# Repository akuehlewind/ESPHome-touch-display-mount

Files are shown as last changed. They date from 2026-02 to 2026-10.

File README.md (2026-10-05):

# ESPHome Home Assistant Touch Panel – CYD, Guition 4.0 and External ILI9341






> [!TIP]
> **Want to build this kind of Home Assistant display, but with a much more powerful and user-friendly setup?**
>
> This repository gives you ready-to-flash YAML configurations and 3D-printable mounts. **Tessera** is a separate project by Max Gramser whose first version started from this repository and has since taken the idea much further: a visual drag-and-drop editor inside Home Assistant, multiple pages, richer controls, centralized screen management, broad display support, and normally no YAML or MQTT required.
>
> I am genuinely impressed by what Max and the community have built. If you want the most capable and polished version of this concept, this is the project I recommend.
>
> **[Discover Tessera: the next-level Home Assistant touchscreen project](https://github.com/MaxGramser/homeassistant_espscreen)**

**About this project:** This repository focuses on a straightforward DIY approach with ready-to-flash ESPHome configurations and 3D-printable mounts for Home Assistant touch panels. It supports the popular Cheap Yellow Display (ESP32-2432S028), the 4.0-inch Guition ESP32-4848S040C_I, and a standalone ILI9341 with external ESP32.

For the 2.8-inch displays, the repository also includes an adjustable 3D-printable enclosure. The existing mounts are designed for the CYD and standalone ILI9341 configurations; a Guition-specific mount is not included yet.

Multiple mounting options are supported:

- Desk Mount – for tabletop installation
- Under-Desk Mount – for installation underneath a desk or shelf
- Wall Mount – for wall installation (CYD version only)
- Flush Mount – for in-wall installation (EU electrical box compatible)

The enclosure can therefore be used as a compact Home Assistant control panel for desks, walls, or mounted underneath furniture.

------------------------------------------------------------------------

The ESP32-2432S028 Cheap Yellow Display is transformed into a tiltable Home Assistant control panel powered by ESPHome and LVGL.

The goal of this project is to create a clean, wall- or desk-mounted smart control panel that integrates seamlessly with Home Assistant.  
It features a modern LVGL-based UI, real-time state synchronization, and optional direct Home Assistant service calls.

The enclosure is designed for:

- Clean cable routing  
- Adjustable viewing angle (±35° tilt)  
- Minimal footprint  
- Professional, integrated appearance  

Three hardware variants are supported:

- ✅ **ESP32-2432S028 (Cheap Yellow Display / CYD)**
- ✅ **Standalone ILI9341 + External ESP32 wiring variant**
- ✅ **Guition ESP32-4848S040C_I (4.0-inch, 480×480, capacitive touch)** — home-like UI; firmware support only for now

The ESP32-2432S028 integrates the ESP32, ILI9341 display, touchscreen controller, and backlight circuitry on a single board.  
It is commonly known as the **Cheap Yellow Display (CYD)** in the maker community and is the easiest option for this project.

Some CYD boards use an ILI9342 panel. The existing CYD home-like YAML contains complete display/orientation presets for both ILI9341 and ILI9342; ILI9341 at 0 degrees remains active by default. USB connector type alone does not identify the controller. See the [hardware selection notes](esphome/home-like/README.md#picking-your-hardware-variant).

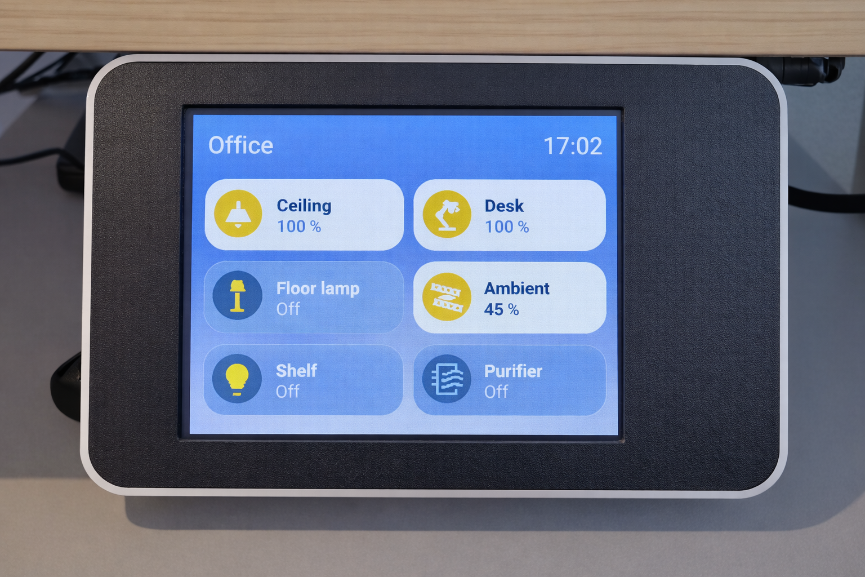
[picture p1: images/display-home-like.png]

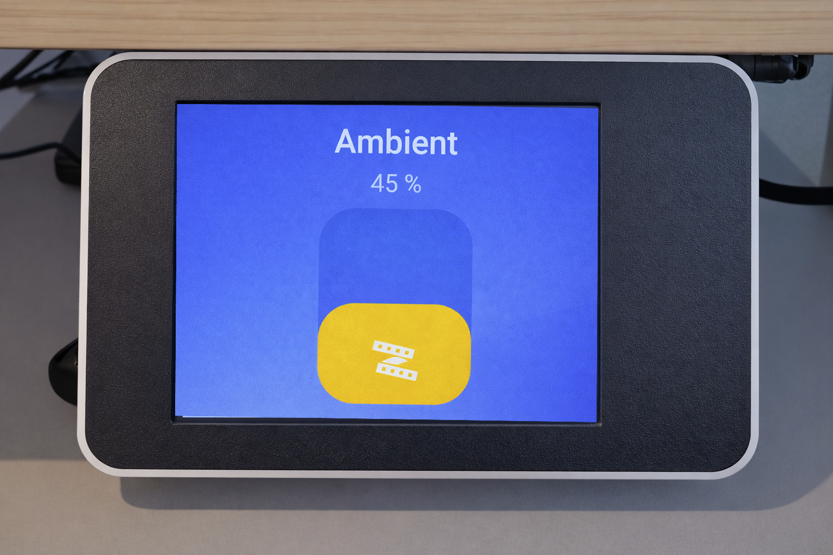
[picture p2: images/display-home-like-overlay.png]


### Guition ESP32-4848S040C_I

The Guition variant uses the same home-like interaction model in a larger 2×4 grid with eight configurable tiles. The tested orientation places the USB-C connector at the bottom.

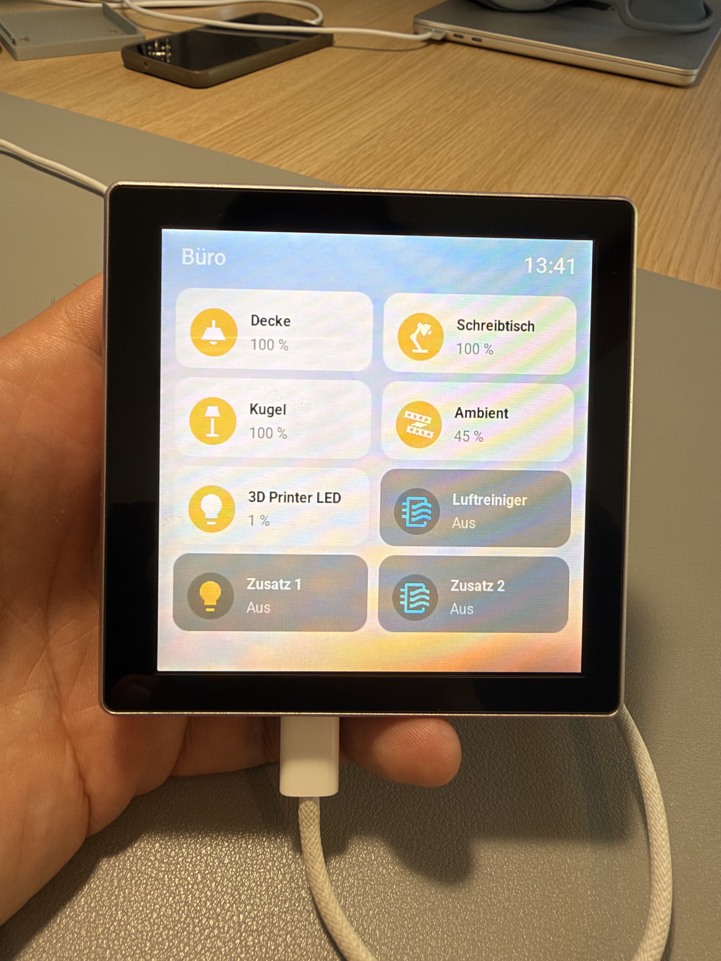
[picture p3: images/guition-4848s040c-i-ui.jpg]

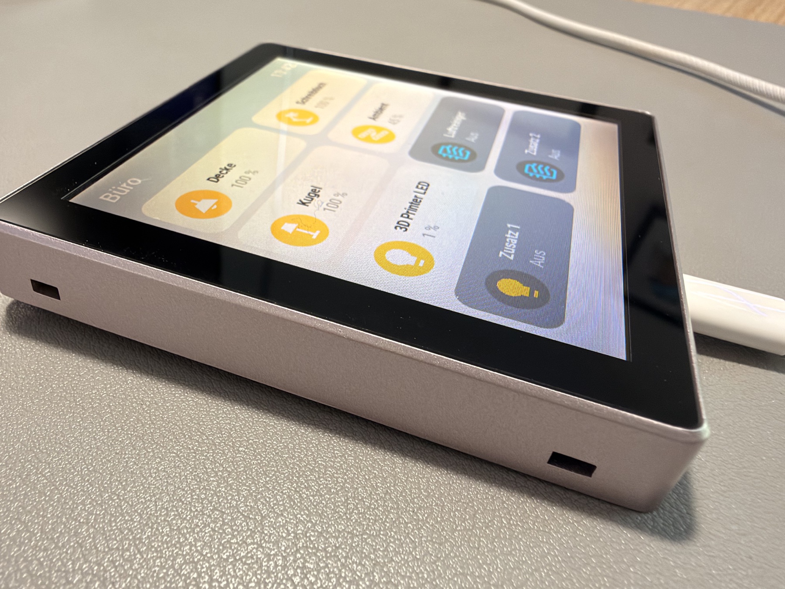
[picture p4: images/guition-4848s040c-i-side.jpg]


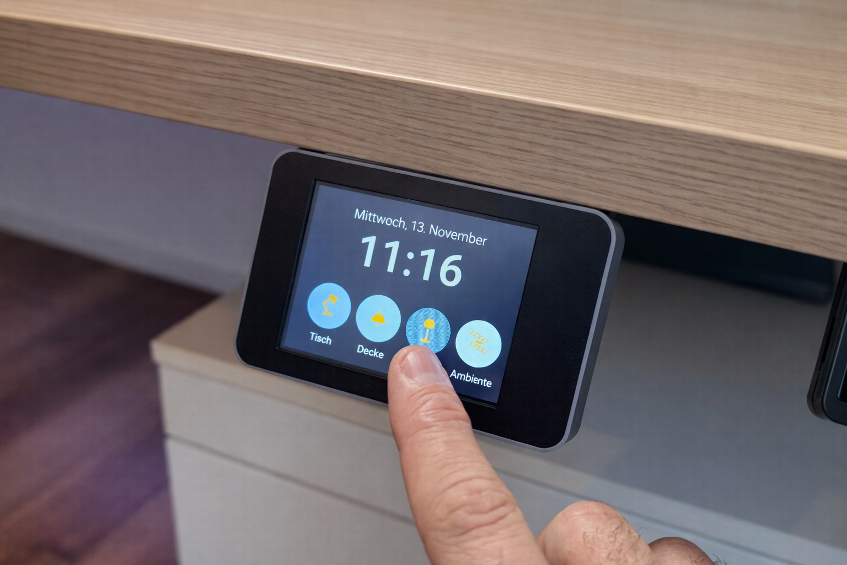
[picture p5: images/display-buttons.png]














## Demo
https://github.com/user-attachments/assets/68709d8e-21ec-4851-bf73-70f583027390

Note: The video quality looks worse than in real life because the display refresh rate interferes with the camera frame rate when filming the screen. In reality the UI looks much smoother and cleaner.

---

# 🆕 Architecture Overview (LVGL-Based UI)

This project uses ESPHome LVGL instead of a classic display lambda approach.

### Core Concepts

- UI rendered fully using LVGL widgets
- 4 configurable buttons in the simple UI, or 6/8 configurable tiles in the home-like UI
- Real-time state mirroring from Home Assistant
- Central `ui_refresh` script keeps UI synchronized
- Optional direct Home Assistant service calls
- Action sensor for automation-based control

### Two Control Modes

#### 1️⃣ Direct Mode (Default – Plug & Play)

If `DIRECT_ACTIONS` is set to `"true"` (default):

- Touch publishes an action string
- AND directly calls a Home Assistant service  
  (default: `light.toggle`)

No Home Assistant automations required.

#### 2️⃣ Automation Mode

If `DIRECT_ACTIONS` is set to `"false"`:

- Touch ONLY publishes an action string
- You implement behavior in Home Assistant automations

Trigger example:
```
Entity: sensor.smartdisplay_action
To: btn1_press
```

### Overlay Control Layer

The UI contains a secondary overlay layer used for interactive controls.

When a tile is long-pressed:

1. The overlay opens
2. The control type is determined (brightness / percentage / cover position / climate temperature)
3. For color-capable lights, the brightness overlay can open a color/temperature picker
4. Slider interaction updates Home Assistant
5. Closing the overlay returns to the tile grid

This keeps the tile UI clean while still allowing detailed control.

# ⚙️ Requirements

- Home Assistant installed
- ESPHome Add-on installed
- **ESPHome 2026.9.0 or newer** is required by encrypted OTA in all five configs. Existing devices need the [OTA migration](#encrypted-ota-and-migration) before using the final config wirelessly.
- Home Assistant 2026.2+
- Basic ESPHome knowledge
- 3D printer access (optional)

---

# 🧪 Tested With

The current home-like integration was hardware-tested with:

- **ESPHome 2026.9.0** and **Home Assistant 2026.2+**
- ESP32-2432S028 (Cheap Yellow Display / CYD) with ILI9341
- Guition ESP32-4848S040C_I with ST7701S RGB display and GT911 capacitive touch
- all existing tile actions and overlays, localized OFF confirmation, auto-dim/wake, touch alignment and encrypted OTA migration

Earlier releases were also tested on the standalone ILI9341 + XPT2046 wiring variant. The ILI9342 contribution author reported testing all four orientations; the integrated ILI9342 profile has not been independently hardware-verified by the maintainer.

# ⚠️ IMPORTANT -- Enable "Actions" in Home Assistant

Because this project uses:

```
homeassistant.action → light.toggle
```

You must allow the ESPHome device to perform Home Assistant service calls.

### How to enable:

1. Open Home Assistant  
2. Go to **Settings**  
3. Click **Devices & Services**  
4. Open the **ESPHome integration**  
5. Select your device  
6. Enable:

> "Allow the device to perform Home Assistant actions"

Without this setting, direct control will not work.

---

# ✨ Features

- LVGL-based UI (lockscreen or tile layout depending on configuration)
- 2×3 configurable tile layout on 320×240 hardware and 2×4 on the 480×480 Guition (home-like UI)
- Long-press per tile: value overlay (brightness / fan speed / cover position / climate temperature) or independent entity action
- Real-time state synchronization with Home Assistant
- Optional direct Home Assistant service calls
- Automation-based mode supported
- Adjustable 3D-printed enclosure
- Multiple mounting options: desk mount, under-desk mount, wall mount, and flush mount
- Hidden cable routing
- Works with CYD, Guition ESP32-4848S040C_I, or external ESP32 wiring

------------------------------------------------------------------------

# 📦 Hardware

## Option A -- ESP32-2432S028 (Cheap Yellow Display Board -- Recommended)

| Part | Price | Comment |
|---|---|---|
| ESP32-2432S028			 | 15$ | 2.8" ILI9341 with integrated ESP |
| 2x M4 3.5x16 screw (flathead)| 0.10$ | Screws to connect the mount case with the base  |

Advantages:

-   Single USB cable
-   Clean installation
-   No manual wiring
-   Widely available under the name "Cheap Yellow Display"

| ESP32-2432S028 | PIN | Comment |
|---|---|---|
| LCD | | |
| clk_pin | GPIO14 | SPI LCD Clock |
| mosi_pin | GPIO13 | SPI LCD MOSI (sometimes also labeled as SDI) |
| miso_pin 	 		 | GPIO12 | SPI LCD MISO (sometimes also labeled as SDO	 |
| cs_pin | GPIO15 | Display CS |
| dc_pin | GPIO2 | Display DC |
| Touchscreen | | |
| clk_pin | GPIO25 | SPI Touchscreen Clock |
| mosi_pin | GPIO32 | SPI Touchscreen MOSI (sometimes also labeled as DIN) |
| miso_pin | GPIO39 | SPI Touchscreen MISO (sometimes also labeled as DO)  |
| cs_pin | GPIO33 | Touchscreen CS |
| interrupt_pin | GPIO36 | Touchscreen Interrupt |
| LED | | |
| ledc | GPIO21 | Backlight LED display |
| ledc | GPIO4 | Onboard LED (not used for this project) |

------------------------------------------------------------------------

### Power connection (CYD)

For the mount enclosure the side USB connector of the CYD is **not used**.

Instead the included power cable can be used.  
The **red and black wires provide 5V and GND** and can easily be connected to an old USB-A cable.

Typical setup:

1. Cut an old USB cable
2. Connect **5V (red)** and **GND (black)** to the CYD power cable
3. Route the cable through the enclosure
4. Solder or use small wire connectors

This keeps the enclosure compact and avoids having a visible or protruding USB connector on the side.

If the USB port was used directly, the enclosure would need to be wider or the connector would remain visible.

⚠️ Important: The CYD often has multiple identical JST connectors, but they do not share the same pinout. Make sure to use the connector labeled VIN / 5V. Other connectors may be labeled 3.3V, and connecting 5V there can damage the board.



## Option B -- Standalone Display + ESP32

| Part | Price | Comment |
|---|---|---|
| 2.8" ILI9341 			 | 8$ | 2.8" ILI9341 |
| ESP32 Wroom 32D 		 | 8$ | or some ESP32 |
| 2x M4 3.5x16 screw (flathead)| 0.10$ | Screws to connect the mount case with the base  |

Requires manual wiring according to the YAML pin configuration.

Use the wiring table below, which shows how to put everything together.

| ILI9341 | PIN  ESP32 | Comment |
|---|---|---|
| GND | GND | Ground |
| VCC | 3.3V | Power |
| LCD | | |
| SCK | GPIO18 | SPI LCD Clock |
| SDI (MOSI) | GPIO23 | SPI LCD MOSI (sometimes also labeled as SDI) |
| SDO (MISO) 	 	 | GPIO19 | SPI LCD MISO (sometimes also labeled as SDO	 |
| CS | GPIO27 | Display CS |
| D/C | GPIO26 | Display DC |
| RESET | GPIO16 | Display Reset |
| Touchscreen | | |
| T_CLK | GPIO25 | SPI Touchscreen Clock |
| T_DO | GPIO35 | SPI Touchscreen MISO (sometimes also labeled as DO) |
| T_DIN | GPIO32 | SPI Touchscreen MOSI (sometimes also labeled as DIN)  |
| T_CS | GPIO33 | Touchscreen CS |
| T_IRQ | GPIO34 | Touchscreen Interrupt |
| LED | | |
| ledc | GPIO4 | Backlight LED display |

------------------------------------------------------------------------

## Option C -- Guition ESP32-4848S040C_I

The Guition is an all-in-one ESP32-S3 board with a 4.0-inch 480×480 ST7701S RGB display, GT911 capacitive touchscreen, 16 MB flash, and 8 MB octal PSRAM. Use `esphome/home-like/guition-4848s040c-i/home-like.yaml`; its display timings, touch transform, and USB-C-down orientation are already configured.

No manual display wiring is required. The existing 2.8-inch printable enclosures do not fit this board.

------------------------------------------------------------------------

# 🚀 Installation

1.  Open ESPHome in Home Assistant
2.  Create a new device
3.  Copy the appropriate YAML file
4.  Edit the **USER CONFIG / substitutions** section at the top of the YAML (entities, labels, icons)
5.  Copy `esphome/secrets.yaml.example` to `secrets.yaml` **in the same directory as the chosen YAML** and fill in your credentials
6.  Flash the device; for an existing password-based installation, follow [OTA migration](#encrypted-ota-and-migration)

Available YAML variants (pick **one UI** for your **hardware**):

> **ESPHome version:** all configs require **ESPHome 2026.9.0+**. The CYD ILI9341 and Guition home-like configurations have been verified on hardware; see [Tested With](#-tested-with) for the remaining hardware scope.

### Cheap Yellow Display (ESP32-2432S028 / CYD)
- `esphome/home-like/cyd-2432s028/home-like.yaml` – 2x3 “tiles” UI (wallpaper + tiles) — actively maintained
- `esphome/buttons/cyd-2432s028/buttons.yaml` – lockscreen with 4 round buttons (simple / legacy)

### External display wiring (any ESP32 + ILI9341 + XPT2046)
- `esphome/home-like/ili9341-external-esp32/home-like.yaml` – 2x3 “tiles” UI (wallpaper + tiles) — actively maintained
- `esphome/buttons/ili9341-external-esp32/buttons.yaml` – lockscreen with 4 round buttons (simple / legacy)

### Guition ESP32-4848S040C_I
- `esphome/home-like/guition-4848s040c-i/home-like.yaml` – 2x4 home-like UI with 8 tiles — actively maintained and hardware-tested

> Tip: The `home-like.yaml` file downloads orientation-specific background images at build time from a pinned repository revision.
> For a full reference of all tile substitutions and copy-paste examples, see [`esphome/home-like/TILE_CONFIGURATION.md`](esphome/home-like/TILE_CONFIGURATION.md).
> Three images are included:
> - `smartdisplay_background.png` — used for 0° (landscape) and 180° (landscape flipped)
> - `smartdisplay_background_90.png` — used for 90° (portrait) and 270° (portrait flipped)
> - `smartdisplay_background_480.png` — square Guition background
>
> The active image is selected via the `BG_IMAGE` substitution. On the 320×240 variants it belongs to the selected orientation preset; the Guition config uses its fixed square background.

------------------------------------------------------------------------

### Assets (downloaded at build time)

The icon font and home-like wallpapers download during compilation, so they do not need to be copied alongside the YAML for the default setup. Credentials still belong in `secrets.yaml` next to that YAML. Existing Google Fonts entries also need network access at build time.

- **Material Design Icons font**: `MDI_FONT_URL` points to `materialdesignicons-webfont.ttf` at release **v7.4.47** of [Templarian/MaterialDesign-Webfont](https://github.com/Templarian/MaterialDesign-Webfont) (Apache 2.0).
  - If you change icons in the YAML, ensure the glyph list contains them.
- **Background images (home-like UI)**:
  - `esphome/home-like/images/smartdisplay_background.png` — landscape (0° and 180°), included.
  - `esphome/home-like/images/smartdisplay_background_90.png` — portrait (90° and 270°), included.
  - `esphome/home-like/images/smartdisplay_background_480.png` — 480×480 Guition, included.
  - Selected via the `BG_IMAGE` substitution; the 320×240 variants tie it to the active orientation preset.
  - Every `ASSET_BASE` is pinned to an immutable repository commit under `esphome/home-like`, so it does not follow changes on `main`. The 320×240 variants use `9ffa5dfddf695150ad0388f5f5e2bcf786772195`; the Guition variant uses `cb3531a7fdf057d4b7273d1feba648162bcfd5c9`.

For local home-like assets, copy that UI's `images/` and `fonts/` folders next to the chosen YAML and set these substitutions:

```yaml
ASSET_BASE: '.'
MDI_FONT_URL: 'fonts/materialdesignicons-webfont.ttf'
```

The buttons UI only needs the font override and local `fonts/` folder; it has no wallpaper. These overrides do not replace the Google Fonts downloads.

### Encrypted OTA and migration

Current configs use `ota: - platform: esphome` with `encryption:`, inheriting `smartdisplay_api_key` from API encryption. Keep the existing API key.

For firmware that only supports password-based OTA, use **two wireless installs** with ESPHome 2026.9.x:

1. In your local config, temporarily replace OTA `encryption:` with `password: !secret ota_password`. Keep the existing password in the adjacent `secrets.yaml` and API encryption enabled. Install, reboot, and verify the log says `Encryption: offered, plaintext accepted`.
2. Replace OTA `password:` with the bare `encryption:` block below, then install again. Verify `Encryption: required`. Subsequent OTA updates use encryption; the unused OTA password secret can now be removed.

```yaml
ota:
  - platform: esphome
    encryption:
```

Do not combine OTA `password:` and `encryption:`. The first transfer to old firmware is plaintext. Alternatively, install the final encrypted config directly over USB/serial. See [ESPHome's migration instructions](https://esphome.io/components/ota/esphome/#enabling-encryption-on-an-existing-device).

# ⚙️ UI mapping (USER CONFIG)

Your config choice defines the UI style:

## `buttons.yaml` (lockscreen like buttons)
- Buttons: BTN1..BTN4
- Action strings: `btn1_press` .. `btn4_press`
- Default direct action (if `DIRECT_ACTIONS: "true"`): `light.toggle` on `BTN*_ENTITY`



## `home-like.yaml` (tiles)
- Tiles: TILE1..TILE6 on 320×240 variants; TILE1..TILE8 on Guition
- Action strings follow the configured tile range, e.g. `tile1_press` through `tile8_press` and the corresponding `tileN_long_press` events
- Each tile can optionally call a Home Assistant service directly (e.g. light toggle, fan preset toggle, cover open/close, cover position, or climate target temperature).
- Per-tile OFF label is configurable via `TILE*_LABEL_OFF` (e.g. "Off" / "Aus").
- Optional `TILEn_CONFIRM_OFF: "true"` guards short taps that would turn off or close a supported entity; the default is `"false"`. Cancellation emits no event and performs no action. Acceptance publishes `tileN_confirmed_off` and performs an explicit off/close action instead of a toggle. See [supported actions and limitations](esphome/home-like/TILE_CONFIGURATION.md#short-tap-off-confirmation), including automation-only mode and unprotected long presses.

### Long-Press Behavior

Each tile's long-press mode is configured via `TILE*_LONGPRESS`:

| Mode | Behavior |
|---|---|
| `slider` | Opens a value overlay (brightness / fan speed / cover position / climate temperature) |
| `action` | Fires a different HA entity than the short tap |
| `none` | Only publishes the `tileN_long_press` event, no direct action |

**Slider mode** — configure with `TILE*_LONGPRESS_SLIDER` and `TILE*_LONGPRESS_OFF_VALUE`:

| Tile Type | Overlay Control |
|---|---|
| light | Brightness slider; color/temperature picker when supported by the HA light entity |
| fan | Speed / percentage slider |
| cover | Position slider |
| climate | Thermostat ring for target temperature |

**Action mode** — configure with `TILE*_LONGPRESS_ACTION`, `TILE*_LONGPRESS_ACTION_TYPE`, and optionally `TILE*_LONGPRESS_ACTION_SERVICE`. The action entity can be a completely different entity than the short tap target — useful for e.g. triggering a scene or script on long press while toggling a light on short press.

In all modes, the `tileN_long_press` event is always published to `sensor.smartdisplay_action` so Home Assistant automations can react to it independently.




------------------------------------------------------------------------

# 🧠 System Flow

### Direct Mode

For a guarded home-like short tap that would switch an entity off, confirmation happens before step 2. Acceptance publishes `tileN_confirmed_off`; cancellation stops the flow.

1. Button pressed  
2. Action string published  
3. Home Assistant service called  
4. Entity state updated  
5. Mirrored back into ESPHome  
6. UI refreshed  

### Automation Mode

The same short-tap gate replaces the normal event with `tileN_confirmed_off` after acceptance. The automation must handle that event with an explicit off/close service, not a toggle.

1. Button pressed  
2. Action string published  
3. Home Assistant automation triggers  
4. Automation controls device  
5. State mirrored back  

------------------------------------------------------------------------

# 🔧 Customization

For most setups, you only need to edit the **USER CONFIG / substitutions** section in the YAML.

You can also:

-   Add more buttons / pages
-   Change service calls (the default is `light.toggle`)
-   Modify fonts and icon glyphs
-   Adjust colors / theme
-   Date localization can be adjusted in the ui_refresh script (days[] / months[] arrays).
-   Adjust transforms for your panel

For home-like touch alignment, use the matching hardware profile and ORIENTATION preset first. LVGL rotates the display and touch coordinates together; touchscreen transforms correct the controller's native axes and do not need to match a display transform. Tune `TOUCH_CAL_*` for your panel.

------------------------------------------------------------------------
# Troubleshooting

### White screen after ESPHome update (2026.4+)

If the display stays **completely white** after updating ESPHome but the device still connects to Home Assistant, the cause is a breaking change in ESPHome 2026.4: the `ili9xxx` display platform was deprecated in favor of `mipi_spi`.

The current configs use `mipi_spi` and require ESPHome 2026.9.0+ for encrypted OTA. Upgrade the builder and follow the OTA migration above; reverting only the display platform does not make these configs compatible with older releases.

---

### Corrupted / garbled display output

If the display shows **corrupted graphics, horizontal lines, or random pixels**, the most common cause is a **different display controller on your Cheap Yellow Display**.

Most CYD boards use **ILI9341**, but some variants ship with **ST7789** or **ILI9342**.  
If the driver in ESPHome does not match the controller, the display output may look broken.

For a confirmed ILI9342 panel, use the existing `esphome/home-like/cyd-2432s028/home-like.yaml`. In **DISPLAY / ORIENTATION PRESETS**, comment out the active ILI9341 block and uncomment one complete ILI9342 block for the required orientation. No separate ILI9342 YAML is needed and no calculated substitutions are involved.

Diagonal stripes can indicate a mismatch between the native panel dimensions and driver. Check the board/controller information; neither that symptom nor a USB-C/Micro-USB connector arrangement is definitive identification. ST7789 boards need a separately verified configuration and are not covered by the ILI9341/ILI9342 selector. The selector applies to the CYD home-like config, not the buttons or external-wiring variants.

---

### `Invalid offsets.` / won't compile on ESPHome 2026.6+

If validation fails on the `dimensions:` line of the display with:

```
display.mipi_spi: Invalid offsets.
```

this is the ESPHome 2026.6 change to `mipi_spi`: a `transform:` block on the display combined with swapped (rotated) `dimensions:` is no longer accepted. **The configs in this repo are already fixed for this** — rotation is now handled by LVGL:

- the display is driven at its **native** size (240 × 320 for ILI9341; 320 × 240 for ILI9342) with **no** rotation transform on the display
- rotation is set via `LVGL_ROTATION` in the chosen ORIENTATION preset, which feeds `rotation:` in the `lvgl:` block (LVGL rotates the display **and** the touch coordinates together)

If you copied an older YAML, update your device configuration, compile with ESPHome 2026.9.0+, and install it using the appropriate migration path above.

---

### Display rotated / mirrored

If the UI appears **rotated, mirrored, or upside down**, use the built-in **DISPLAY / ORIENTATION PRESETS** in the substitutions section at the top of `home-like.yaml`.

The CYD home-like config provides eight complete presets: four orientations for ILI9341 and four for ILI9342. Uncomment exactly one complete block and comment out all others. The external ILI9341 config continues to provide its four orientation presets.

> Note: touch calibration values (`TOUCH_CAL_*`) are device-specific. The presets include approximate values that may need tuning after flashing.

**LVGL manages rotation** for both the display and the touchscreen. Do not add display rotation to compensate for touch alignment; use the matching profile and preset. The resulting rotation is supplied through `LVGL_ROTATION`:

```yaml
# in the active display/orientation preset
LVGL_ROTATION: "90"   # 0 / 90 / 180 / 270
```

If touch is mirrored or axes are swapped relative to the display, check the touchscreen axis correction for your selected controller. These values correct raw XPT2046 coordinates against the native panel; the ILI9341 example below is not a universal ILI9342 profile:

```yaml
TOUCH_SWAP_XY: "false"
TOUCH_MIRROR_X: "true"
TOUCH_MIRROR_Y: "false"
```

After changing a display/orientation preset, verify touch targets and calibration on the physical panel. Current configs require ESPHome 2026.9.0+.

------------------------------------------------------------------------

# 🖨 3D Printing

See the `/3d_print` folder for STL files and Fusion 360 source files.

Multiple mount options are available:

- **Desk Mount** – for tabletop installation
- **Under-Desk Mount** – for installation underneath a desk or shelf
- **Wall Mount** – for wall installation (CYD version only)
- **Flush Mount** – for in-wall installation (CYD version only, EU electrical box compatible)

Desk mount and Under-Desk mount use the same enclosure parts and adjustable tilt mechanism.  
Print the main enclosure parts and choose one mount type depending on your setup.

Designed for:

- Desk mounting
- Under-desk mounting
- Wall mounting
- Flush mounting (EU electrical box compatible)
- Adjustable viewing angle
- Hidden cable routing

------------------------------------------------------------------------

# ⚠️ Disclaimer

This is a hobby project and considered work-in-progress.

Feel free to fork, remix and improve it.

# Other





# More projects
Looking for more cool projects using this display? Check out the [LoctekMotion Touch Display GitHub repository](https://github.com/3DJupp/LoctekMotion-TouchDisplay)! This awesome project takes the same 2.8" ILI9341 touchscreen setup and repurposes it—not for lights, but for controlling a height-adjustable Flexispot desk with ease. If you're into smart home automation and custom builds, it's definitely worth a look!

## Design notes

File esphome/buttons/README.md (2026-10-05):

# Buttons UI — Simple Lockscreen Layout

This folder contains the original "buttons" UI: a minimal lockscreen with a clock and 4 round toggle buttons.

Requires **ESPHome 2026.9.0 or newer**. Existing password-based devices need the [two-step wireless OTA migration](../../README.md#encrypted-ota-and-migration), or a USB/serial install.

> **Looking for the full-featured UI?**
> The actively maintained version is in [`../home-like/`](../home-like/).
> It offers a 2×3 or 2×4 tile grid depending on hardware, per-tile entity types, brightness/fan/cover sliders, long press actions, orientation presets, and much more.

---

## What this UI does

- Displays a clock (time + date)
- 4 configurable round buttons, each mapped to a Home Assistant entity
- Each tap publishes `btn1_press` … `btn4_press` to `sensor.smartdisplay_action`
- Optional direct HA service calls (light.toggle by default)

## What it does NOT have

- No tile grid or wallpaper background
- No per-button entity types (lights only by default)
- No value/state display per button
- No brightness, fan speed, or cover position sliders
- No long press actions
- No orientation presets
- No auto-dim or night mode
- No per-tile OFF confirmation or ILI9342 model selector; those belong to the home-like UI

## When to use it

If you want the absolute simplest possible setup — just 4 buttons that toggle lights — this is the quickest way to get started. Configuration is minimal: set 4 entity IDs and flash.

For anything beyond basic toggles, use the [home-like UI](../home-like/) instead.

## Picking your hardware variant

You need to pick **one** YAML file that matches your hardware:

### `cyd-2432s028/buttons.yaml` — Cheap Yellow Display (CYD)

The **ESP32-2432S028**, commonly known as the **Cheap Yellow Display (CYD)**, is an all-in-one board with the ESP32, ILI9341 display, XPT2046 touchscreen, and backlight all on a single PCB. Just one USB cable, no manual wiring.

### `ili9341-external-esp32/buttons.yaml` — Standalone ILI9341 + external ESP32

Use this file if you have a **separate ILI9341 display module** wired to a generic ESP32 board. Requires manual wiring according to the pin table in the main README.

---

## Credentials — secrets.yaml

All sensitive values (API key and WiFi credentials) are referenced via ESPHome's `!secret` system. Encrypted OTA inherits the API encryption key.

Copy [`../secrets.yaml.example`](../secrets.yaml.example) to `secrets.yaml` **in the same directory as the chosen YAML**, and fill in your values. For example, `cyd-2432s028/buttons.yaml` needs `cyd-2432s028/secrets.yaml`. `secrets.yaml` is gitignored and never committed. Keep the old OTA password secret only for the first wireless migration step.

---

## Assets downloaded at build time

The icon font downloads at build time through `MDI_FONT_URL`, pinned to Material Design Webfont **v7.4.47**. The buttons UI has **no wallpaper and needs no background image**.

For a local icon font, copy the bundled `fonts/` folder next to the chosen YAML and set:

```yaml
MDI_FONT_URL: 'fonts/materialdesignicons-webfont.ttf'
```

Existing Google Fonts entries still require network access at build time. Both button configurations are compile-validated with ESPHome 2026.9.0; the current integration was hardware-tested with the home-like CYD UI, not this legacy UI.

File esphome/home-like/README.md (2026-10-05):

# Home-Like UI — Tile Grid Layout

This folder contains the main, actively maintained UI: a wallpaper-backed tile grid inspired by modern smart home apps. The 320×240 variants use a 2×3 grid; the Guition 480×480 variant uses a 2×4 grid.

Requires **ESPHome 2026.9.0 or newer**. For existing password-based devices, follow the [two-step wireless OTA migration](../../README.md#encrypted-ota-and-migration), or install over USB/serial.

> **Looking for the simple version?**
> A minimal lockscreen with 4 round buttons is available in [`../buttons/`](../buttons/).

---

## What this UI does

- 6 or 8 configurable tiles, depending on the hardware variant, each with icon, title, and value line
- Supports lights, fans, switches, covers, climate entities, scenes, and scripts per tile
- Real-time state synchronization with Home Assistant
- Long press opens a value overlay (brightness / fan speed / cover position / climate temperature)
- Color-capable lights can open a color/temperature picker from the brightness overlay
- Long press can alternatively fire a completely different HA entity than the short tap
- Four orientation presets on the 320×240 variants; a hardware-tested USB-C-down orientation on Guition
- Auto-dim and night mode with configurable brightness levels
- Optional direct HA service calls or automation-only mode
- Optional short-tap OFF confirmation per tile; defaults to disabled and leaves long presses independent

---

## Configuration reference

All tile substitutions are documented in [TILE_CONFIGURATION.md](TILE_CONFIGURATION.md). It covers:

- Every substitution key with description and default value
- All tap actions, long press modes, and value modes explained
- Complete copy-paste examples for: light, switch, cover, fan, climate, scene, script
- Long press examples: slider overlay and independent entity action
- How to find and format Material Design Icons

Start there if you are setting up tiles for the first time.

---

## Picking your hardware variant

You need to pick **one** YAML file that matches your hardware:

### `cyd-2432s028/home-like.yaml` — Cheap Yellow Display (CYD)

The **ESP32-2432S028**, commonly known as the **Cheap Yellow Display (CYD)**, is an all-in-one board with the ESP32, ILI9341 display, XPT2046 touchscreen, and backlight all on a single PCB. It is the easiest and most common choice for this project — just one USB cable, no manual wiring.

Use this file if you have a standalone ESP32-2432S028 board.

In the **DISPLAY / ORIENTATION PRESETS** section, enable exactly one complete block for the controller and orientation you need. `ILI9341 / 0 degrees` is active by default; every ILI9342 block is fully commented out. There is no separate ILI9342 copy and no template logic to edit. Check the actual controller: USB connector type alone is not definitive, and ST7789 variants are not supported by these presets.

| Setting | ILI9341 (default) | ILI9342 |
|---|---|---|
| Native dimensions | 240 x 320 | 320 x 240 |
| Display data rate / color order | 10 MHz / BGR, preserving existing behavior | 40 MHz / RGB |
| LVGL rotation relative to orientation | +90 degrees, modulo 360 | +180 degrees, modulo 360 |
| Touch swap X/Y | false | true |
| Touch mirror X / Y | true / false | true / true in landscape; false / false in portrait |
| Touch calibration X / Y minima | 280 / 340 | 340 / 280 |

The ILI9342 contributor reported testing all four orientations on hardware. Its touch mirror settings are empirical, particularly in portrait; a source audit cannot independently verify touch alignment. Hardware verification of the integrated profile by the maintainer is **pending**, so check touch targets and calibration on your own panel. ILI9341 remains the default with its existing settings and behavior.

### `ili9341-external-esp32/home-like.yaml` — Standalone ILI9341 + external ESP32

Use this file if you have a **separate ILI9341 display module** wired to a generic ESP32 board (e.g. ESP32 DevKit / Wroom 32D). This requires manual wiring according to the pin table in the main README.

### `guition-4848s040c-i/home-like.yaml` — Guition 4.0-inch 480×480

Use this file for the **Guition ESP32-4848S040C_I** with ESP32-S3, ST7701S RGB display, and GT911 capacitive touchscreen. It provides eight tiles in a 2×4 grid. The display timings, touch transform, full LVGL buffer, and USB-C-down orientation were verified on physical hardware with ESPHome 2026.9.0.

This variant currently adds firmware/UI support only. The repository's existing 3D-printable enclosures are sized for the 2.8-inch displays and do not fit the Guition board.

---

## Credentials — secrets.yaml

All sensitive values (API key and WiFi credentials) are referenced via ESPHome's `!secret` system, so nothing sensitive is stored in the YAML itself. Encrypted OTA inherits the API key.

Copy [`../secrets.yaml.example`](../secrets.yaml.example) to `secrets.yaml` **next to the chosen YAML**, and fill in your values. For example, a config kept at `cyd-2432s028/home-like.yaml` needs `cyd-2432s028/secrets.yaml`. When pasted into Device Builder, use the directory containing that device's YAML.

```yaml
wifi_ssid: "Your WiFi Network Name"
wifi_password: "your_wifi_password"
smartdisplay_api_key: "your_32_byte_base64_api_key"
wifi_ap_password: "your_fallback_password"
```

`secrets.yaml` is gitignored and never committed.

Retain the existing `ota_password` secret only while performing step 1 of the [wireless migration](../../README.md#encrypted-ota-and-migration); the final encrypted config does not use it.

---

## Assets downloaded at build time

The default config downloads its icon font and wallpapers while compiling. No local asset folders are required for this setup; `secrets.yaml` is still required alongside the YAML.

| Substitution | Source | Required by |
|---|---|---|
| `MDI_FONT_URL` | Templarian/MaterialDesign-Webfont release `v7.4.47` | Icon glyphs on every tile |
| `ASSET_BASE` | This repository's `esphome/home-like` at the immutable commit selected in each YAML | Background wallpaper |

The 320×240 variants pin `ASSET_BASE` to commit `9ffa5dfddf695150ad0388f5f5e2bcf786772195`. The Guition variant pins it to the asset commit `cb3531a7fdf057d4b7273d1feba648162bcfd5c9` containing its square background.

- `smartdisplay_background.png` — used for 0° and 180° (landscape)
- `smartdisplay_background_90.png` — used for 90° and 270° (portrait)
- `smartdisplay_background_480.png` — used by the square Guition variant

The active image is selected by `BG_IMAGE` in the chosen display/orientation preset inside the YAML.

To use the bundled assets locally, copy this folder's `fonts/` and `images/` next to your chosen YAML and override:

```yaml
ASSET_BASE: '.'
MDI_FONT_URL: 'fonts/materialdesignicons-webfont.ttf'
```

These overrides only localize the icon font and wallpapers. The existing Google Fonts entries still require network access during compilation.

## Short-tap confirmation

Set `TILEn_CONFIRM_OFF: "true"` for a tile that should ask before turning off or closing. It is independent of `TILEn_TAP_ACTION` and defaults to `"false"`. Cancellation, tapping outside, or display dimming emits no event and performs no action. Acceptance publishes `tileN_confirmed_off` and uses an explicit `turn_off`/`close_cover` action, so a state change while the dialog is open cannot turn the entity back on.

The alert question, actions, color controls, and climate labels are localizable through the `UI_*` substitutions. Confirmation questions contain a `{title}` placeholder, which may be moved to match the target language's word order. A complete German example is included in [the configuration reference](TILE_CONFIGURATION.md#interface-text-and-localization).

The guard covers built-in toggle behavior for lights, fans, switches and covers, `fan_toggle_preset`, matching toggle services, and explicit off/close services. Unknown states are treated as potentially on. Scenes, scripts, climate tiles and opaque custom services are not gated because the display cannot know whether they switch something off. Long presses remain independent and are **not protected**. In automation-only mode, handle `tileN_confirmed_off` with an idempotent off/close service. See [the full scope and example](TILE_CONFIGURATION.md#short-tap-off-confirmation).

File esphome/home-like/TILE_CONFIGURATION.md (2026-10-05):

# Tile Configuration Reference

This document explains every substitution in `home-like.yaml` and provides copy-paste examples for all supported entity types.

---

## How substitutions work

ESPHome substitutions are compile-time text replacements. There is no runtime logic in the substitution block — every `${TILE1_...}` reference in the YAML is replaced with the value you set before the firmware is compiled and flashed. This means:

- You cannot use `if/else` in substitutions
- Changes require a reflash
- The firmware is fully self-contained after flashing

---

## Global settings

| Key | Default | Description |
|-----|---|---|
| `DIRECT_ACTIONS` | `"true"` | `true` = device calls HA services directly on tap. `false` = only publishes the action event, you handle it in HA automations. |
| `ROOM_NAME` | `"Office"` | Text shown in the top-left header. |
| `TIME_24H` | `"true"` | `true` = 24h clock, `false` = 12h with AM/PM. |
| `AUTO_DIM` | `"true"` | Enable backlight auto-dimming after inactivity. |
| `AUTO_DIM_TIMEOUT` | `"10"` | Seconds of no touch before dimming. |
| `MAX_BRIGHTNESS` | `"100"` | Backlight brightness (%) when active. |
| `DIM_BRIGHTNESS` | `"40"` | Backlight brightness (%) when dimmed. |
| `NIGHT_MODE` | `"true"` | Use a lower brightness level during night hours. |
| `NIGHT_START_HOUR` | `"22"` | Hour (0–23) when night mode starts. |
| `NIGHT_END_HOUR` | `"7"` | Hour (0–23) when night mode ends. |
| `NIGHT_DIM_BRIGHTNESS` | `"18"` | Backlight brightness (%) during night hours. |

---

## Interface text and localization

All built-in overlay text is configured through `UI_*` substitutions. This keeps translations in the editable configuration and does not require language-specific branches in the implementation. Tile titles and on/off labels remain configurable per tile.

The confirmation questions use `{title}` as a required placeholder. It may appear anywhere in the sentence, so languages can use their natural word order. For example:

```yaml
UI_CONFIRM_OFF_QUESTION: "{title} ausschalten?"
UI_CONFIRM_CLOSE_QUESTION: "{title} schließen?"
UI_CONFIRM_FALLBACK_TITLE: "dieses Gerät"
UI_CANCEL: "Abbrechen"
UI_TURN_OFF: "Ausschalten"
UI_CLOSE: "Schließen"
```

The complete interface text set is:

| Substitution | Default | Used for |
|---|---|---|
| `UI_CONFIRM_OFF_QUESTION` | `Turn off {title}?` | Light, fan and switch confirmation |
| `UI_CONFIRM_CLOSE_QUESTION` | `Close {title}?` | Cover confirmation |
| `UI_CONFIRM_FALLBACK_TITLE` | `this device` | Missing tile title in a confirmation |
| `UI_CANCEL` | `Cancel` | Non-destructive alert action |
| `UI_TURN_OFF` | `Turn off` | Destructive OFF action |
| `UI_CLOSE` | `Close` | Destructive cover action |
| `UI_COLOR` | `Color` | Color picker heading |
| `UI_TEMPERATURE_SHORT` | `Temp.` | Color-temperature heading |
| `UI_BRIGHTNESS` | `Brightness` | Brightness heading |
| `UI_CURRENT` | `Current` | Current climate value |
| `UI_HUMIDITY` | `Humidity` | Climate humidity value |
| `UI_SET_TO` | `SET TO` | Climate target value |
| `UI_CLIMATE_MODE_OFF` | `Off` | Climate mode |
| `UI_CLIMATE_MODE_HEAT` | `Heat` | Climate mode |
| `UI_CLIMATE_MODE_COOL` | `Cool` | Climate mode |
| `UI_CLIMATE_MODE_HEAT_COOL` | `Heat/Cool` | Climate mode |
| `UI_CLIMATE_MODE_AUTO` | `Auto` | Climate mode |
| `UI_CLIMATE_MODE_DRY` | `Dry` | Climate mode |
| `UI_CLIMATE_MODE_FAN` | `Fan` | Climate mode |

Changes are applied when the firmware is compiled. Keep translations concise for the target display and test long tile titles in the confirmation alert.

---

## Per-tile substitutions

Each tile has the same set of keys, just with a different number. The 320×240 variants provide TILE1 … TILE6; the Guition 480×480 variant provides TILE1 … TILE8.

### Basic settings

| Key | Description |
|-----|---|
| `TILE*_ENTITY` | The Home Assistant entity this tile controls (e.g. `light.living_room`). |
| `TILE*_STATE_ENTITY` | Entity used to determine active/inactive visual state. Usually the same as `TILE*_ENTITY`. Set to a different entity if you want the tile to reflect a group or a related sensor. |
| `TILE*_TITLE` | Text label shown on the tile. |
| `TILE*_ICON` | Material Design Icons Unicode glyph. Find icons at [pictogrammers.com/library/mdi](https://pictogrammers.com/library/mdi/) — click an icon and copy the Unicode value (e.g. `U+F0769` → `"\U000F0769"`). |
| `TILE*_TYPE` | Entity type: `light` \| `fan` \| `switch` \| `scene` \| `script` \| `cover` \| `climate`. Controls tap behavior, value display, and slider type in auto mode. |
| `TILE*_TAP_ACTION` | What happens on short tap — see [Tap actions](#tap-actions) below. |
| `TILE*_CONFIRM_OFF` | `"false"` by default. Set `"true"` to enable the [short-tap confirmation guard](#short-tap-off-confirmation), independently of the tap action. |
| `TILE*_LONGPRESS` | What happens on long press — see [Long press modes](#long-press-modes) below. |
| `TILE*_VALUE_MODE` | How the value line below the title is rendered — see [Value modes](#value-modes) below. |
| `TILE*_LABEL_OFF` | Text shown in the value line when the entity is off / inactive. |
| `TILE*_LABEL_ON` | Text shown in the value line when `VALUE_MODE` is `text` and entity is on. |

### Colors

All colors are 24-bit hex in the format `"0xRRGGBB"`.

| Key | Description |
|-----|---|
| `TILE*_CIRCLE_ACTIVE_COLOR` | Icon circle background when active. |
| `TILE*_CIRCLE_DISABLED_COLOR` | Icon circle background when inactive. |
| `TILE*_ICON_ACTIVE_COLOR` | Icon glyph color when active. |
| `TILE*_ICON_DISABLED_COLOR` | Icon glyph color when inactive. |
| `TILE*_BG_ACTIVE_COLOR` | Tile background when active. |
| `TILE*_BG_DISABLED_COLOR` | Tile background when inactive. |
| `TILE*_TITLE_ACTIVE_COLOR` | Title text color when active. |
| `TILE*_TITLE_DISABLED_COLOR` | Title text color when inactive. |
| `TILE*_VALUE_ACTIVE_COLOR` | Value text color when active. |
| `TILE*_VALUE_DISABLED_COLOR` | Value text color when inactive. |

### Advanced settings (short tap)

| Key | Default | Description |
|-----|---|---|
| `TILE*_TAP_SERVICE` | `""` | Override the HA service called on tap (e.g. `"light.toggle"`). Leave empty to use the default for the tile type. |
| `TILE*_TAP_PARAM_KEY` | `""` | Extra parameter key for the service call (e.g. `"preset_mode"`). |
| `TILE*_TAP_PARAM_VAL` | `""` | Extra parameter value (e.g. `"Auto"`). |

### Advanced settings (long press — slider mode)

Only relevant when `TILE*_LONGPRESS` is set to `"slider"`.

| Key | Default | Description |
|-----|---|---|
| `TILE*_LONGPRESS_SLIDER` | `"auto"` | Slider type: `auto` \| `brightness` \| `percentage` \| `cover_position` \| `climate_temperature`. `auto` picks the right type based on `TILE*_TYPE`. |
| `TILE*_LONGPRESS_OFF_VALUE` | `"0"` | Initial slider position (0–100) shown when the entity is currently off. |

### Advanced settings (climate tiles)

Only relevant when `TILE*_TYPE` is set to `"climate"`.

| Key | Default | Description |
|-----|---|---|
| `TILE*_CLIMATE_MIN_TEMP` | `"5.0"` | Minimum target temperature shown in the thermostat overlay. |
| `TILE*_CLIMATE_MAX_TEMP` | `"30.0"` | Maximum target temperature shown in the thermostat overlay. |
| `TILE*_CLIMATE_STEP` | `"0.5"` | Step size for the thermostat ring and +/- buttons. Values below `0.5` are rounded up to `0.5`, so the UI always adjusts in whole or half-degree steps. |
| `TILE*_CLIMATE_CURRENT_TEMP_ATTRIBUTE` | `"current_temperature"` | Home Assistant attribute used for the current room temperature. |
| `TILE*_CLIMATE_TARGET_TEMP_ATTRIBUTE` | `"temperature"` | Home Assistant attribute used for the target temperature. |
| `TILE*_CLIMATE_HUMIDITY_ATTRIBUTE` | `"current_humidity"` | Home Assistant attribute used for humidity. Leave the default if the entity does not provide humidity. |

### Advanced settings (long press — action mode)

Only relevant when `TILE*_LONGPRESS` is set to `"action"`.

| Key | Default | Description |
|-----|---|---|
| `TILE*_LONGPRESS_ACTION` | `""` | HA entity to call on long press. Can be completely different from `TILE*_ENTITY`. |
| `TILE*_LONGPRESS_ACTION_TYPE` | `""` | Entity type of the long press target: `light` \| `fan` \| `switch` \| `scene` \| `script` \| `cover`. Leave empty to inherit from `TILE*_TYPE`. |
| `TILE*_LONGPRESS_ACTION_SERVICE` | `""` | Service to call (default is `activate`/`turn_on`). Set e.g. `"light.toggle"` to toggle instead. |

---

## Tap actions

| Value | Behavior |
|---|---|
| `auto` | Picks the best action for the tile type: `toggle` for light/fan/switch/cover, `activate` for scene/script. Climate tiles do not have a default tap action; use `TILE*_TAP_SERVICE` if you want short tap behavior. |
| `toggle` | Toggles the entity (light.toggle / fan.toggle / switch.toggle / cover open↔close). |
| `activate` | Turns on / activates the entity (scene.turn_on / script.turn_on / light.turn_on / cover.open_cover). |
| `fan_toggle_preset` | If fan is ON: turns it off. If fan is OFF: turns it on and sets a preset mode (configure with `TAP_PARAM_KEY` / `TAP_PARAM_VAL`). |
| `custom` | Use `TAP_SERVICE` + `TAP_PARAM_KEY` / `TAP_PARAM_VAL` for a fully custom service call. |

---

## Long press modes

| Value | Behavior |
|---|---|
| `slider` | Opens a value overlay with a slider. Configure with `TILE*_LONGPRESS_SLIDER` and `TILE*_LONGPRESS_OFF_VALUE`. |
| `action` | Fires a different HA entity than the short tap. Configure with `TILE*_LONGPRESS_ACTION*`. |
| `none` | No direct action — only publishes `tileN_long_press` to HA so you can react in automations. |

In all modes, the event `tileN_long_press` is always published to `sensor.smartdisplay_action` in Home Assistant.

For light tiles in `slider` mode, the brightness overlay automatically shows a color-ring button when `DIRECT_ACTIONS` is `"true"` and Home Assistant reports a supported color mode (`hs`, `rgb`, `rgbw`, `rgbww`, `xy`) or color temperature mode (`color_temp`). The color detail view can send `light.turn_on` with `color_name`, `color_temp_kelvin`, and the current brightness percentage. If the light only supports color or only supports color temperature, the Color/Temp tab switch is hidden and only the supported controls are shown. No extra tile substitutions are required.

For climate tiles in `slider` mode, the thermostat overlay sends `climate.set_temperature` with the configured target temperature. The min/max range, step size, and Home Assistant attribute names are configured through the `TILE*_CLIMATE_*` substitutions. The mode pill cycles through the climate entity's supported `hvac_modes` and sends `climate.set_hvac_mode` when `DIRECT_ACTIONS` is `"true"`.

---

## Value modes

| Value | Behavior |
|---|---|
| `auto` | Picks automatically: `brightness` for lights, `percentage` or `preset` for fans, `climate` for climate entities, `text` for everything else. |
| `brightness` | Shows brightness as a percentage (e.g. `80 %`). When off, shows `LABEL_OFF`. |
| `percentage` | Shows fan speed as a percentage. When off, shows `LABEL_OFF`. |
| `preset` | Shows the fan preset_mode attribute. When off, shows `LABEL_OFF`. |
| `climate` | Shows the target temperature, falling back to current temperature if no target is available. When off, shows `LABEL_OFF`. |
| `text` | Shows `LABEL_ON` when on, `LABEL_OFF` when off. For scenes/scripts, always shows `LABEL_ON`. |

---

## Short-tap OFF confirmation

Enable the guard independently for each tile:

```yaml
TILE1_TAP_ACTION: "auto"
TILE1_CONFIRM_OFF: "true"
```

For lights, fans, switches and covers, a tap that would turn the entity on or open it still runs immediately and publishes `tile1_press`. A tap that would turn it off or close it opens a confirmation dialog instead. This applies to:

- built-in `auto` and `toggle` actions
- `fan_toggle_preset`
- matching `light.toggle`, `fan.toggle`, `switch.toggle` and `cover.toggle` service overrides
- matching explicit `turn_off` or `cover.close_cover` service overrides

If the state is `unknown` or `unavailable`, a guarded toggle asks for confirmation rather than risking an unintended OFF action. Cancelling, tapping outside the dialog, or display dimming performs no action and emits no event. Long presses are unaffected.

After acceptance, direct mode publishes `tile1_confirmed_off` and calls an explicit `light.turn_off`, `fan.turn_off`, `switch.turn_off` or `cover.close_cover`. It never sends a delayed toggle, because the entity state may have changed while the dialog was open.

With `DIRECT_ACTIONS: "false"`, the display only publishes the event. The Home Assistant automation must therefore handle both paths:

```yaml
# tile1_press: normal immediate action, such as turning an off light on
# tile1_confirmed_off: explicit light.turn_off; do not use light.toggle here
```

Scenes, scripts, climate tiles and opaque custom services are not gated because their effect cannot be inferred safely from the tile configuration.

---

## Home Assistant events

Every tap publishes a short-lived state to `sensor.smartdisplay_action`:

| Event | Trigger |
|---|---|
| `tile1_press` … `tile6_press` | Short tap on tile 1–6 |
| `tile1_confirmed_off` … `tile6_confirmed_off` | Accepted OFF/close confirmation for tile 1–6 |
| `tile1_long_press` … `tile6_long_press` | Long press on tile 1–6 |

The state resets to `""` after 500ms. In HA automations, trigger on `state` → `to: "tile1_press"` etc. A confirmed OFF action publishes only `tileN_confirmed_off`, not `tileN_press`.

---

## Complete examples

### Light — toggle + brightness slider

```yaml
TILE1_ENTITY: "light.living_room_ceiling"
TILE1_STATE_ENTITY: "light.living_room_ceiling"
TILE1_TITLE: "Ceiling"
TILE1_ICON: "\U000F0769"          # mdi:ceiling-light
TILE1_TYPE: "light"
TILE1_TAP_ACTION: "auto"          # toggles the light
TILE1_LONGPRESS: "slider"         # long press opens brightness slider
TILE1_VALUE_MODE: "auto"          # shows brightness % when on, "Off" when off
TILE1_LABEL_OFF: "Off"
TILE1_LABEL_ON: "On"
# colors
TILE1_CIRCLE_ACTIVE_COLOR: "0xFEC600"
TILE1_CIRCLE_DISABLED_COLOR: "0x7B7B6F"
TILE1_ICON_ACTIVE_COLOR: "0xFFFFFF"
TILE1_ICON_DISABLED_COLOR: "0xFEC600"
TILE1_BG_ACTIVE_COLOR: "0xFFFFFF"
TILE1_BG_DISABLED_COLOR: "0x939391"
TILE1_TITLE_ACTIVE_COLOR: "0x000000"
TILE1_TITLE_DISABLED_COLOR: "0xFFFFFF"
TILE1_VALUE_ACTIVE_COLOR: "0x7A7A7C"
TILE1_VALUE_DISABLED_COLOR: "0xD9D9D9"
# advanced
TILE1_TAP_SERVICE: ""
TILE1_TAP_PARAM_KEY: ""
TILE1_TAP_PARAM_VAL: ""
TILE1_LONGPRESS_SLIDER: "auto"    # auto = brightness for lights
TILE1_LONGPRESS_OFF_VALUE: "0"
TILE1_LONGPRESS_ACTION: ""
TILE1_LONGPRESS_ACTION_TYPE: ""
TILE1_LONGPRESS_ACTION_SERVICE: ""
```

---

### Switch — simple toggle, no slider

```yaml
TILE2_ENTITY: "switch.office_power_strip"
TILE2_STATE_ENTITY: "switch.office_power_strip"
TILE2_TITLE: "Power Strip"
TILE2_ICON: "\U000F06FF"          # mdi:power-socket-eu
TILE2_TYPE: "switch"
TILE2_TAP_ACTION: "auto"          # toggles the switch
TILE2_LONGPRESS: "none"           # long press only sends event, no slider
TILE2_VALUE_MODE: "text"          # shows "On" / "Off"
TILE2_LABEL_OFF: "Off"
TILE2_LABEL_ON: "On"
# colors
TILE2_CIRCLE_ACTIVE_COLOR: "0xFEC600"
TILE2_CIRCLE_DISABLED_COLOR: "0x7B7B6F"
TILE2_ICON_ACTIVE_COLOR: "0xFFFFFF"
TILE2_ICON_DISABLED_COLOR: "0xFEC600"
TILE2_BG_ACTIVE_COLOR: "0xFFFFFF"
TILE2_BG_DISABLED_COLOR: "0x939391"
TILE2_TITLE_ACTIVE_COLOR: "0x000000"
TILE2_TITLE_DISABLED_COLOR: "0xFFFFFF"
TILE2_VALUE_ACTIVE_COLOR: "0x7A7A7C"
TILE2_VALUE_DISABLED_COLOR: "0xD9D9D9"
# advanced
TILE2_TAP_SERVICE: ""
TILE2_TAP_PARAM_KEY: ""
TILE2_TAP_PARAM_VAL: ""
TILE2_LONGPRESS_SLIDER: "auto"
TILE2_LONGPRESS_OFF_VALUE: "0"
TILE2_LONGPRESS_ACTION: ""
TILE2_LONGPRESS_ACTION_TYPE: ""
TILE2_LONGPRESS_ACTION_SERVICE: ""
```

---

### Cover — open/close toggle + position slider

```yaml
TILE3_ENTITY: "cover.living_room_blinds"
TILE3_STATE_ENTITY: "cover.living_room_blinds"
TILE3_TITLE: "Blinds"
TILE3_ICON: "\U000F111C"          # mdi:blinds
TILE3_TYPE: "cover"
TILE3_TAP_ACTION: "auto"          # opens if closed, closes if open
TILE3_LONGPRESS: "slider"         # long press opens position slider
TILE3_VALUE_MODE: "auto"          # shows "Open" / "Closed" (text mode for covers)
TILE3_LABEL_OFF: "Closed"
TILE3_LABEL_ON: "Open"
# colors — blue theme for covers
TILE3_CIRCLE_ACTIVE_COLOR: "0x00C5EC"
TILE3_CIRCLE_DISABLED_COLOR: "0x7B7B6F"
TILE3_ICON_ACTIVE_COLOR: "0xFFFFFF"
TILE3_ICON_DISABLED_COLOR: "0x00C5EC"
TILE3_BG_ACTIVE_COLOR: "0xFFFFFF"
TILE3_BG_DISABLED_COLOR: "0x939391"
TILE3_TITLE_ACTIVE_COLOR: "0x000000"
TILE3_TITLE_DISABLED_COLOR: "0xFFFFFF"
TILE3_VALUE_ACTIVE_COLOR: "0x7A7A7C"
TILE3_VALUE_DISABLED_COLOR: "0xD9D9D9"
# advanced
TILE3_TAP_SERVICE: ""
TILE3_TAP_PARAM_KEY: ""
TILE3_TAP_PARAM_VAL: ""
TILE3_LONGPRESS_SLIDER: "auto"    # auto = cover_position for covers
TILE3_LONGPRESS_OFF_VALUE: "0"
TILE3_LONGPRESS_ACTION: ""
TILE3_LONGPRESS_ACTION_TYPE: ""
TILE3_LONGPRESS_ACTION_SERVICE: ""
```

---

### Fan — toggle preset on tap + speed slider on long press

```yaml
TILE4_ENTITY: "fan.air_purifier"
TILE4_STATE_ENTITY: "fan.air_purifier"
TILE4_TITLE: "Purifier"
TILE4_ICON: "\U000F0D43"          # mdi:air-purifier
TILE4_TYPE: "fan"
TILE4_TAP_ACTION: "fan_toggle_preset"  # off→on with preset, on→off
TILE4_LONGPRESS: "slider"              # long press opens speed slider
TILE4_VALUE_MODE: "auto"               # shows preset name when on, "Off" when off
TILE4_LABEL_OFF: "Off"
TILE4_LABEL_ON: "On"
# colors — blue theme for fan
TILE4_CIRCLE_ACTIVE_COLOR: "0x00C5EC"
TILE4_CIRCLE_DISABLED_COLOR: "0x7B7B6F"
TILE4_ICON_ACTIVE_COLOR: "0xFFFFFF"
TILE4_ICON_DISABLED_COLOR: "0x00C5EC"
TILE4_BG_ACTIVE_COLOR: "0xFFFFFF"
TILE4_BG_DISABLED_COLOR: "0x939391"
TILE4_TITLE_ACTIVE_COLOR: "0x000000"
TILE4_TITLE_DISABLED_COLOR: "0xFFFFFF"
TILE4_VALUE_ACTIVE_COLOR: "0x7A7A7C"
TILE4_VALUE_DISABLED_COLOR: "0xD9D9D9"
# advanced — fan_toggle_preset requires SERVICE + PARAM
TILE4_TAP_SERVICE: "fan.toggle"
TILE4_TAP_PARAM_KEY: "preset_mode"
TILE4_TAP_PARAM_VAL: "Auto"       # preset to activate when turning on
TILE4_LONGPRESS_SLIDER: "auto"    # auto = percentage for fans
TILE4_LONGPRESS_OFF_VALUE: "0"
TILE4_LONGPRESS_ACTION: ""
TILE4_LONGPRESS_ACTION_TYPE: ""
TILE4_LONGPRESS_ACTION_SERVICE: ""
```

---

### Climate — thermostat ring on long press

```yaml
TILE5_ENTITY: "climate.living_room"
TILE5_STATE_ENTITY: "climate.living_room"
TILE5_TITLE: "Living"
TILE5_ICON: "\U000F0438"          # mdi:radiator
TILE5_TYPE: "climate"
TILE5_TAP_ACTION: "auto"          # no default tap action; use TAP_SERVICE if desired
TILE5_LONGPRESS: "slider"         # long press opens thermostat ring
TILE5_VALUE_MODE: "auto"          # shows target temperature, or current temperature as fallback
TILE5_LABEL_OFF: "Off"
TILE5_LABEL_ON: "Heat"
# colors
TILE5_CIRCLE_ACTIVE_COLOR: "0xFF9F0A"
TILE5_CIRCLE_DISABLED_COLOR: "0x7B7B6F"
TILE5_ICON_ACTIVE_COLOR: "0xFFFFFF"
TILE5_ICON_DISABLED_COLOR: "0xFF9F0A"
TILE5_BG_ACTIVE_COLOR: "0xFFFFFF"
TILE5_BG_DISABLED_COLOR: "0x939391"
TILE5_TITLE_ACTIVE_COLOR: "0x000000"
TILE5_TITLE_DISABLED_COLOR: "0xFFFFFF"
TILE5_VALUE_ACTIVE_COLOR: "0x7A7A7C"
TILE5_VALUE_DISABLED_COLOR: "0xD9D9D9"
# advanced
TILE5_TAP_SERVICE: ""
TILE5_TAP_PARAM_KEY: ""
TILE5_TAP_PARAM_VAL: ""
TILE5_LONGPRESS_SLIDER: "auto"    # auto = climate_temperature for climate tiles
TILE5_LONGPRESS_OFF_VALUE: "0"
TILE5_LONGPRESS_ACTION: ""
TILE5_LONGPRESS_ACTION_TYPE: ""
TILE5_LONGPRESS_ACTION_SERVICE: ""
TILE5_CLIMATE_MIN_TEMP: "5.0"
TILE5_CLIMATE_MAX_TEMP: "30.0"
TILE5_CLIMATE_STEP: "0.5"
TILE5_CLIMATE_CURRENT_TEMP_ATTRIBUTE: "current_temperature"
TILE5_CLIMATE_TARGET_TEMP_ATTRIBUTE: "temperature"
TILE5_CLIMATE_HUMIDITY_ATTRIBUTE: "current_humidity"
```

---

### Scene — activate on tap

```yaml
TILE6_ENTITY: "scene.movie_night"
TILE6_STATE_ENTITY: "scene.movie_night"  # scenes are always "on" so the tile stays active-styled
TILE6_TITLE: "Movie"
TILE6_ICON: "\U000F0E8B"          # mdi:movie-open
TILE6_TYPE: "scene"
TILE6_TAP_ACTION: "auto"          # activates the scene
TILE6_LONGPRESS: "none"
TILE6_VALUE_MODE: "text"          # always shows LABEL_ON for scenes
TILE6_LABEL_OFF: "Scene"
TILE6_LABEL_ON: "Scene"
# colors — green theme
TILE6_CIRCLE_ACTIVE_COLOR: "0x4CAF50"
TILE6_CIRCLE_DISABLED_COLOR: "0x7B7B6F"
TILE6_ICON_ACTIVE_COLOR: "0xFFFFFF"
TILE6_ICON_DISABLED_COLOR: "0x4CAF50"
TILE6_BG_ACTIVE_COLOR: "0xFFFFFF"
TILE6_BG_DISABLED_COLOR: "0x939391"
TILE6_TITLE_ACTIVE_COLOR: "0x000000"
TILE6_TITLE_DISABLED_COLOR: "0xFFFFFF"
TILE6_VALUE_ACTIVE_COLOR: "0x7A7A7C"
TILE6_VALUE_DISABLED_COLOR: "0xD9D9D9"
# advanced
TILE6_TAP_SERVICE: ""
TILE6_TAP_PARAM_KEY: ""
TILE6_TAP_PARAM_VAL: ""
TILE6_LONGPRESS_SLIDER: "auto"
TILE6_LONGPRESS_OFF_VALUE: "0"
TILE6_LONGPRESS_ACTION: ""
TILE6_LONGPRESS_ACTION_TYPE: ""
TILE6_LONGPRESS_ACTION_SERVICE: ""
```

---

### Script — run on tap

```yaml
TILE6_ENTITY: "script.good_morning"
TILE6_STATE_ENTITY: "script.good_morning"
TILE6_TITLE: "Morning"
TILE6_ICON: "\U000F0A72"          # mdi:weather-sunny
TILE6_TYPE: "script"
TILE6_TAP_ACTION: "auto"          # runs the script
TILE6_LONGPRESS: "none"
TILE6_VALUE_MODE: "text"
TILE6_LABEL_OFF: "Run"
TILE6_LABEL_ON: "Run"
# colors — orange theme
TILE6_CIRCLE_ACTIVE_COLOR: "0xFF6F00"
TILE6_CIRCLE_DISABLED_COLOR: "0x7B7B6F"
TILE6_ICON_ACTIVE_COLOR: "0xFFFFFF"
TILE6_ICON_DISABLED_COLOR: "0xFF6F00"
TILE6_BG_ACTIVE_COLOR: "0xFFFFFF"
TILE6_BG_DISABLED_COLOR: "0x939391"
TILE6_TITLE_ACTIVE_COLOR: "0x000000"
TILE6_TITLE_DISABLED_COLOR: "0xFFFFFF"
TILE6_VALUE_ACTIVE_COLOR: "0x7A7A7C"
TILE6_VALUE_DISABLED_COLOR: "0xD9D9D9"
# advanced
TILE6_TAP_SERVICE: ""
TILE6_TAP_PARAM_KEY: ""
TILE6_TAP_PARAM_VAL: ""
TILE6_LONGPRESS_SLIDER: "auto"
TILE6_LONGPRESS_OFF_VALUE: "0"
TILE6_LONGPRESS_ACTION: ""
TILE6_LONGPRESS_ACTION_TYPE: ""
TILE6_LONGPRESS_ACTION_SERVICE: ""
```

---

### Long press — call a different entity

Short tap toggles a light; long press activates a scene.

```yaml
TILE1_ENTITY: "light.living_room"
TILE1_TYPE: "light"
TILE1_TAP_ACTION: "auto"           # short tap: toggle the light
TILE1_LONGPRESS: "action"          # long press: fire a different entity
# ...
TILE1_LONGPRESS_ACTION: "scene.movie_night"
TILE1_LONGPRESS_ACTION_TYPE: "scene"
TILE1_LONGPRESS_ACTION_SERVICE: "" # empty = default activate for scene
```

Short tap toggles a light; long press also toggles a different light.

```yaml
TILE1_LONGPRESS: "action"
TILE1_LONGPRESS_ACTION: "light.bedroom"
TILE1_LONGPRESS_ACTION_TYPE: ""    # empty = inherits "light" from TILE1_TYPE
TILE1_LONGPRESS_ACTION_SERVICE: "light.toggle"  # must set toggle explicitly, default is turn_on
```

---

## Finding Material Design Icons

1. Go to [pictogrammers.com/library/mdi](https://pictogrammers.com/library/mdi/)
2. Search for an icon name
3. Click the icon → copy the Unicode codepoint (e.g. `F0769`)
4. Format it as `"\U000F0769"` (always 8 hex digits, padded with leading zeros)

Make sure the glyph is listed in the `glyphs:` section of the MDI font definition in the YAML (search for `materialdesign_icons`). If you use an icon that is not listed there, it will show as a blank space.

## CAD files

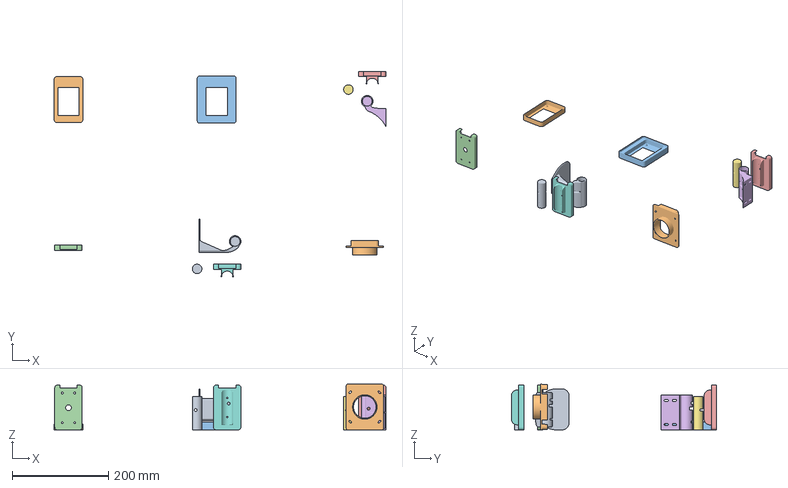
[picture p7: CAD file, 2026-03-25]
3d_print/ESP32-2432S028/touch-display.3mf
688.4 x 425.7 x 94.8 mm
Table Mount.stl x 2
outer-body.stl
outer-body-wide.stl
wall-mount-touch-display.stl
Inner Body.stl x 2
Locking Body.stl x 2
flush-mount-body.stl

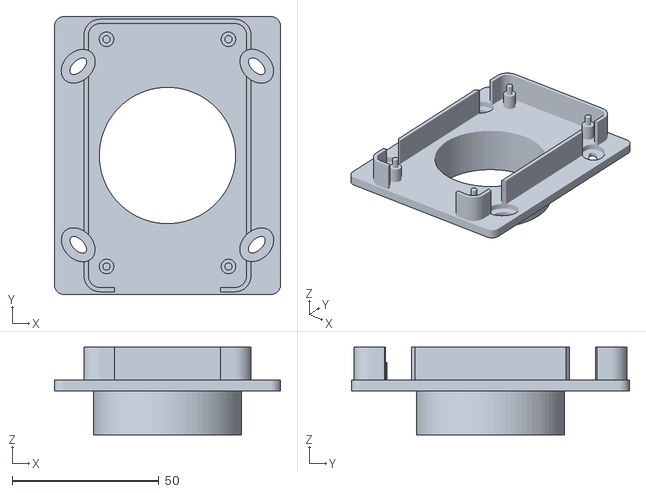
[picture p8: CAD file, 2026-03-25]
3d_print/ESP32-2432S028/variants/flush-mount/flush-mount-body.stl
77.2 x 94.8 x 30.0

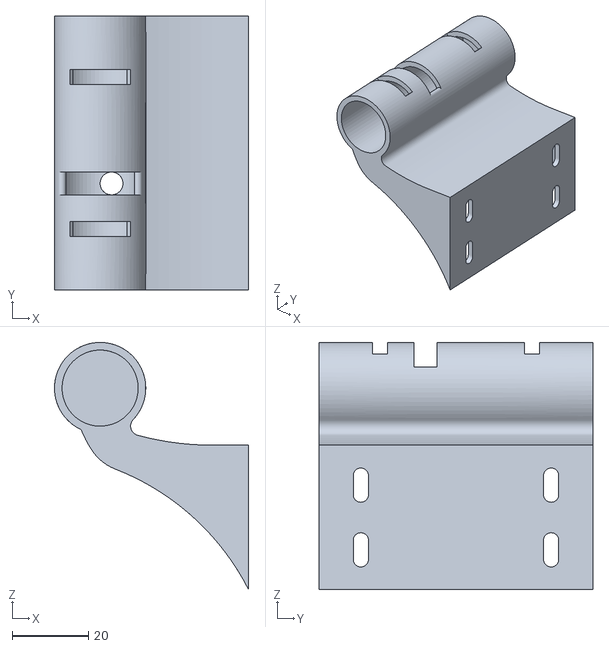
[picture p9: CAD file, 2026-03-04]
3d_print/ESP32-2432S028/variants/under-desk-mount/under-desk-mount.stl
51.0 x 72.0 x 64.9

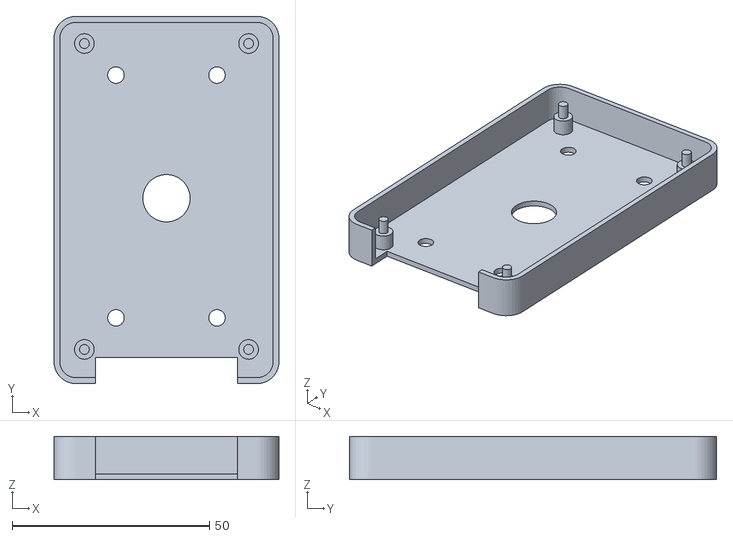
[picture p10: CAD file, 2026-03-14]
3d_print/ESP32-2432S028/variants/wall-mount/wall-mount-touch-display.stl
57.0 x 93.0 x 11.0

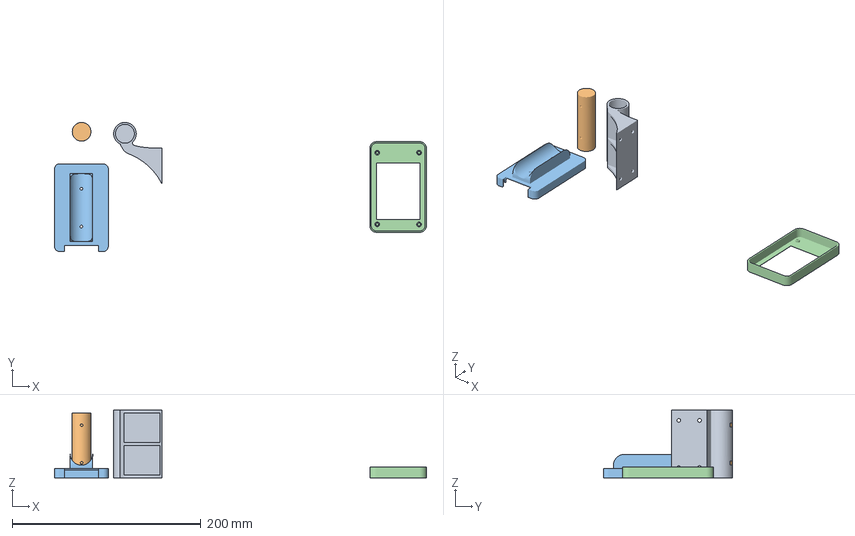
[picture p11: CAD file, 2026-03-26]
3d_print/ILI9341-only-display/touch-display.3mf
394.1 x 136.8 x 72.0 mm
table-mount.stl
locking-body.stl
inner-body.stl
outer-body.stl

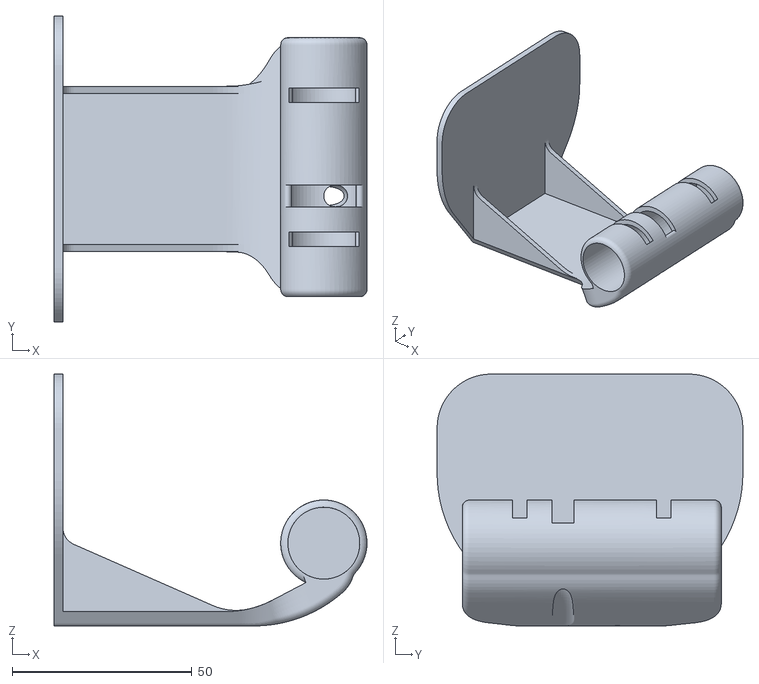
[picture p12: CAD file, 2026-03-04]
3d_print/ILI9341-only-display/variants/desk-mount/desk-mount.stl
87.0 x 85.0 x 70.0

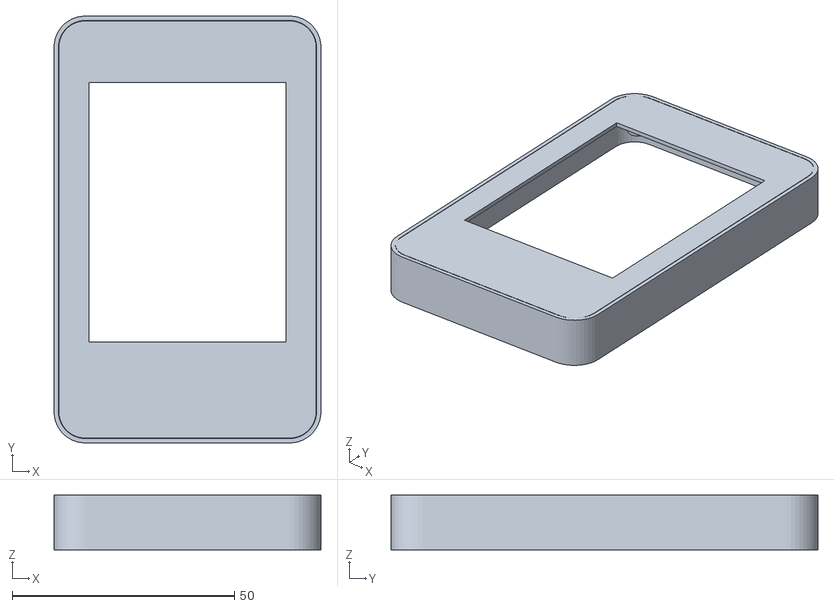
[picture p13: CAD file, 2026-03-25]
3d_print/ESP32-2432S028/outer-body.stl
60.1 x 96.1 x 12.3

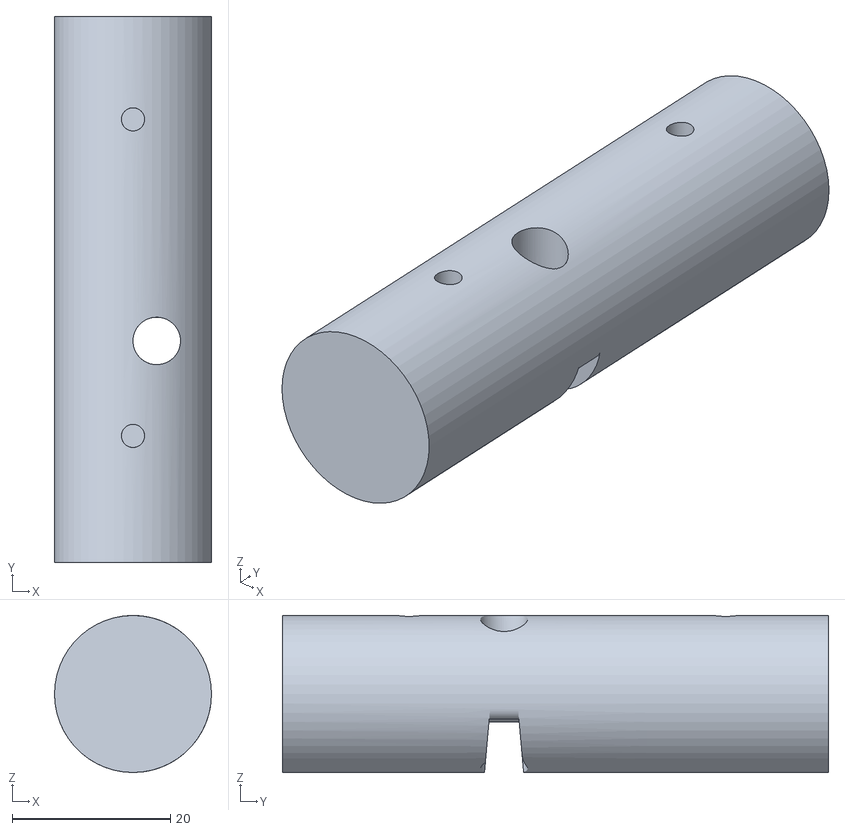
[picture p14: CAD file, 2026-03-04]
3d_print/ILI9341-only-display/locking-body.stl
19.8 x 69.0 x 19.8

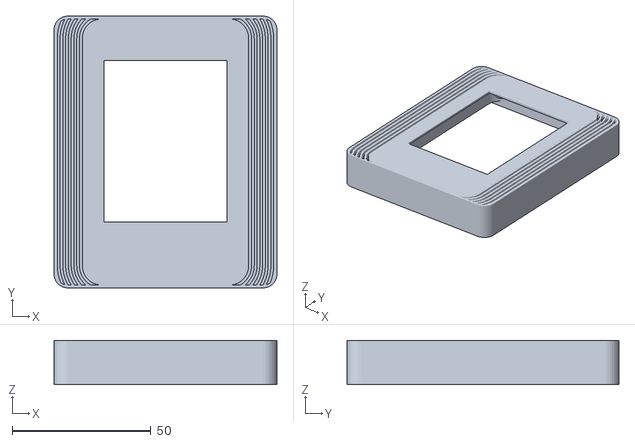
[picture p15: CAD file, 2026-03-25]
3d_print/ESP32-2432S028/outer-body-wide.stl
80.5 x 98.1 x 16.0

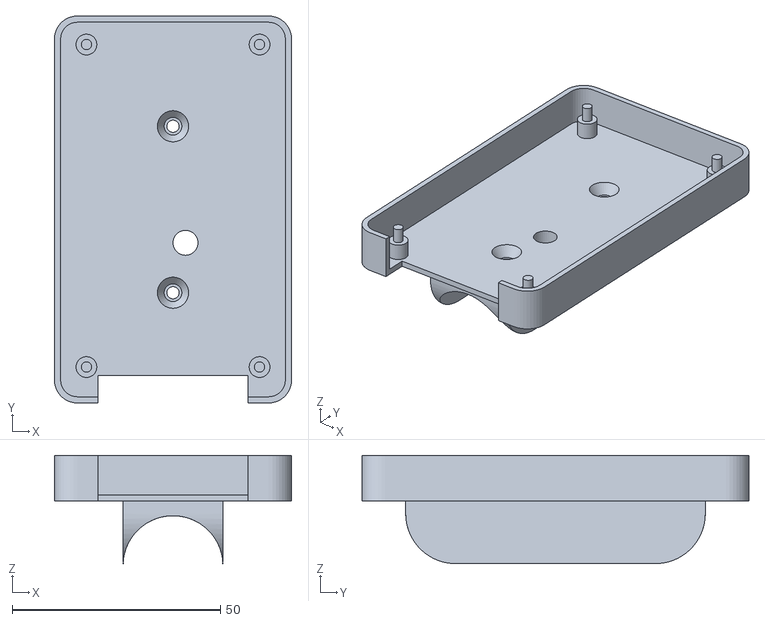
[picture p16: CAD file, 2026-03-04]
3d_print/ESP32-2432S028/inner-body.stl
57.0 x 93.0 x 26.0

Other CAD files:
3d_print/ILI9341-only-display/variants/under-desk-mount/under-desk-mount.stl
3d_print/ESP32-2432S028/variants/desk-mount/desk-stand-touch-display.f3d
3d_print/ESP32-2432S028/variants/flush-mount/flush-mount-touch-display.f3d
3d_print/ESP32-2432S028/variants/under-desk-mount/under-desk-touch-display.f3d
3d_print/ESP32-2432S028/variants/wall-mount/wall-mount-touch-display.f3d

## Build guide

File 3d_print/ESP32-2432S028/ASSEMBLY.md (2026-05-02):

# Assembly Guide – ESP32-2432S028 (CYD)

## Parts to print

| File | Qty | Notes |
|---|-----|---|
| `inner-body.stl` | 1 | Holds the display |
| `outer-body.stl` | 1 | Outer shell |
| `locking-body.stl` | 1 | Connects inner body to the mount and locks the viewing angle |
| Mount variant (see below) | 1 | Pick one from `variants/` |

**Mount variants** (print one):

| Variant | File |
|---|---|
| Desk mount | `variants/desk-mount/desk-mount.stl` |
| Under-desk mount | `variants/under-desk-mount/under-desk-mount.stl` |
| Wall mount | `variants/wall-mount/wall-mount-touch-display.stl` |
| Flush mount (EU box) | `variants/flush-mount/flush-mount-body.stl` |

---

## Assembly steps

### 1. Attach the locking body to the mount

Insert the **locking body** into the round hole of the desk or under-desk mount base.

### 2. Place the inner body

Set the **inner body** on top of the locking body.

### 3. Screw inner body to locking body

Insert the **2× M4 3.5×16 flathead screws** through the openings in the inner body and tighten them into the locking body.

Tighten until the display holds its position firmly but can still be tilted by hand — then adjust to your preferred viewing angle and tighten fully so it stays in place.

### 4. Connect and thread the power cable

The CYD ships with a small JST power cable. Plug the JST connector into the **VIN / 5V port** on the CYD board.

⚠️ The CYD has multiple identical-looking JST connectors with different voltages. Always check the label — connecting 5V to a 3.3V port will damage the board.

Feed the **red and black wires through the cable hole** in the inner body before inserting the display. Once the display is in place this is no longer easy to do.

On the loose end, connect the **red wire to 5V** and the **black wire to GND** of an old USB-A cable. Solder or use small wire connectors.

> The side USB connector on the CYD is not used — routing power via the JST cable keeps the enclosure compact with no protruding connector.

### 5. Insert the display

Slide the CYD board into the inner body with the screen facing forward.

### 6. Close the enclosure

Press the **outer body** onto the inner body until it clicks into place.

---

## Tips

- Print all parts without supports.
- The desk mount and under-desk mount use the same enclosure parts — only the base differs.

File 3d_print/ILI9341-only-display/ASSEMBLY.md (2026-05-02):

# Assembly Guide – Standalone ILI9341 + External ESP32

## Parts to print

| File | Qty | Notes |
|---|-----|---|
| `inner-body.stl` | 1 | Holds the display; has a cutout on the back for pin access |
| `outer-body.stl` | 1 | Outer shell |
| `locking-body.stl` | 1 | Connects inner body to the mount and locks the viewing angle |
| Mount variant (see below) | 1 | Pick one from `variants/` |

**Mount variants** (print one):

| Variant | File |
|---|---|
| Desk mount | `variants/desk-mount/desk-mount.stl` |
| Under-desk mount | `variants/under-desk-mount/under-desk-mount.stl` |

---

## Assembly steps

### 1. Attach the locking body to the mount

Insert the **locking body** into the round hole of the desk or under-desk mount base.

### 2. Place the inner body

Set the **inner body** on top of the locking body.

### 3. Screw inner body to locking body

Insert the **2× M4 3.5×16 flathead screws** through the openings in the inner body and tighten them into the locking body.

Tighten until the display holds its position firmly but can still be tilted by hand — then adjust to your preferred viewing angle and tighten fully so it stays in place.

### 4. Wire up the display

Connect the ILI9341 display and ESP32 according to the wiring table in the [main README](../../README.md#option-b----standalone-display--esp32).

The inner body has a **cutout on the back** so all pins remain accessible from behind once the display is installed — no need to route cables through the body.

### 5. Insert the display

Slide the ILI9341 board into the inner body with the screen facing forward. Route any wiring out through the back cutout.

### 6. Close the enclosure

Press the **outer body** onto the inner body until it clicks into place.

---

## Tips

- Print all parts without supports.
- Keep wire connections as short as practical so they sit neatly behind the display.

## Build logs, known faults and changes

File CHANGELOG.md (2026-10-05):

# Changelog

All notable changes to the ESPHome configs are listed here.
Pure documentation and README updates are not included.

---

## 2026-10-05

### Added
- Home-like UI support for the Guition ESP32-4848S040C_I with ESP32-S3, 4.0-inch 480×480 ST7701S RGB display, GT911 capacitive touch, and eight configurable tiles in a 2×4 layout.
- Hardware-tested USB-C-down display and touch orientation, Guition-specific display timings, full LVGL buffer, and a dedicated 480×480 background image.

### Changed
- Home-like documentation and tile configuration reference now distinguish the six-tile 320×240 variants from the eight-tile Guition variant.

---

## 2026-09-24

### Added
- CYD home-like display/orientation presets for ILI9342 panels, including RGB color order, 40 MHz data rate and contributor-tested touch transforms for all four orientations (#26). ILI9341 remains the active default; all presets are explicit values without template expressions. Thanks @pleasantone.
- Optional per-tile `TILE*_CONFIRM_OFF` guard for home-like short taps (#32 concept). Confirmation is limited to known OFF/close actions, emits a dedicated `tileN_confirmed_off` event and executes an explicit off/close service instead of a delayed toggle. Long presses remain independent. Thanks @pleasantone for the feature proposal.
- Localizable `UI_*` substitutions for confirmation, color and climate overlays, including language-specific confirmation templates with a `{title}` placeholder.

### Changed
- File images now declare `platform: file` for current ESPHome compatibility (#27).
- Material Design Icons and home-like wallpapers are downloaded at build time from pinned sources, with documented local overrides (#29).
- OTA uses encryption inherited from the Home Assistant API key and requires ESPHome 2026.9.0 or newer; documentation includes the two-step wireless migration from password-based OTA (#30).
- The OFF confirmation now uses a compact Home-style alert with a translucent system surface, subtle separators, and text actions instead of large filled buttons.

### Fixed
- Suppressed expected ESP32 strapping-pin warnings for the CYD display pins without changing the board wiring (#28).
- Custom short-tap services now execute when `TILE*_TAP_ACTION` is `custom`, matching the documented behavior.

---

## 2026-06-21

### Fixed
- ESPHome 2026.6 compile failure `display.mipi_spi: Invalid offsets.` on the `dimensions:` line (#23) — `mipi_spi` no longer accepts a display `transform:` combined with swapped/rotated `dimensions:`. Rotation is now handled by LVGL: the display runs at its native 240×320 with no `transform:`, and orientation is driven by `LVGL_ROTATION` feeding `lvgl: rotation:` (LVGL rotates display and touch together). Affects both `cyd-2432s028` and `ili9341-external-esp32` home-like configs. Reported by @Twilek-de and @carla2409; fix approach contributed by @atl285. Thanks!

### Changed
- ORIENTATION presets: `DISPLAY_SWAP_XY` / `DISPLAY_MIRROR_X/Y` replaced by a single `LVGL_ROTATION` (0/90/180/270). Touch transform is now a constant native-axis correction (no longer per-orientation), since LVGL rotates touch coordinates automatically.

---

## 2026-05-31

### Added
- Home-like light color controls: long-press brightness overlays now show a color-ring button for color-capable lights and open a color/temperature detail view with preset colors, Kelvin presets, and a brightness slider for both CYD and external ILI9341 variants. The Color/Temp switch is hidden automatically when a light only supports one mode. Thanks @Dominik-1980 for the initial push on this feature.
- Home-like climate tile support: `TILE*_TYPE: climate` now provides a thermostat-style long-press overlay with target temperature ring, +/- controls, current temperature/humidity display, clickable HVAC mode selection, half-degree temperature steps, live HA sync while open, and per-tile `TILE*_CLIMATE_*` substitutions for range, step size, and HA attribute mapping.

---

## 2026-05-02

### Docs
- Added assembly guides for both hardware variants (`3d_print/ESP32-2432S028/ASSEMBLY.md` and `3d_print/ILI9341-only-display/ASSEMBLY.md`) covering print parts, mounting order, power wiring, and display installation

---

## 2026-04-26

### Fixed
- Duplicate MDI glyph error when the same icon is used on multiple tiles — font glyph list is now driven by a dedicated `MDI_GLYPH_1..6` substitution block instead of the per-tile `TILE*_ICON` variables, so each glyph appears exactly once regardless of how many tiles share it

---

## 2026-04-22

### Fixed
- Display platform migrated from `ili9xxx` to `mipi_spi` — fixes white screen on ESPHome 2026.4+
- Removed `miso_pin` from LCD SPI bus (not required for display, caused issues with newer ESPHome)
- Removed `color_palette: 8BIT` (not supported by `mipi_spi`)

---

## 2026-04-02

### Added
- `TILE*_LONGPRESS` mode selector: `none | slider | action` — replaces the previous implicit dual-mode behavior
- Long-press `action` mode: `TILE*_LONGPRESS_ACTION*` substitutions allow targeting a completely different entity on long press than the short tap
- `secrets.yaml.example` — template for all required secret keys; all YAMLs now use `!secret` references instead of hardcoded placeholders

### Fixed
- Long-press events not appearing in Home Assistant history — publish delay increased from 200ms to 500ms
- Double-tap registered when `DIM_BRIGHTNESS` equals `MAX_BRIGHTNESS` — touch-blocking overlay is now only shown when the display actually dims

### Changed
- `esphome/` folder reorganized: `home-like/` and `buttons/` are now the top-level UI variant folders, each containing `cyd-2432s028/` and `ili9341-external-esp32/` subfolders
- Credentials (`api.encryption.key`, `ota.password`, WiFi) moved to `secrets.yaml` across all variants

---

## 2026-04-01

### Added
- Orientation support for home-like UI: four presets (0° / 90° / 180° / 270°) with correct display transform, touch transform, grid layout, and background image selection

---

## 2026-03-31

### Added
- Cover tile support: `TILE*_TYPE: cover` with open/close tap action and position slider on long press

---

## 2026-03-25

### Added
- Auto-dim night mode: configurable time range during which the display dims to a lower brightness level (`NIGHT_DIM_START` / `NIGHT_DIM_END` / `NIGHT_DIM_BRIGHTNESS`)

---

## 2026-03-13

### Added
- Configurable 12/24h time format via `TIME_24H` substitution

---

## 2026-03-07

### Added
- Long-press control overlay for home-like UI: brightness slider (light), speed slider (fan), position slider (cover)
- Tile substitutions restructured to support per-tile type, tap action, value mode, and color configuration

---

## 2026-02-24

### Added
- Home-like UI variant (`home-like.yaml`): 2×3 tile grid with wallpaper background, icon, title, and value per tile
- Each tile publishes `tileN_press` / `tileN_long_press` action strings to Home Assistant

---

## 2026-02-21

### Changed
- Migrated from display lambda rendering to LVGL-based UI across all variants
- Real-time state mirroring from Home Assistant via `on_state` triggers and central `ui_refresh` script

---

## 2025-02-28

### Fixed
- Display rendering broken since ESPHome 2025.2 (thanks @3DJupp)

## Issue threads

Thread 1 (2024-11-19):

parts

yiannosi, 2024-11-19:
Nice project. Any links for the main parts?

akuehlewind, 2024-11-19:
ESP32 Touchscreen 2,8 Zoll TFT LCD Display ESP-WROOM-32 ILI9341 Resistives Touch-Modul 240 * 320 ESP32-2432S028R Bluetooth WIFI
https://a.aliexpress.com/_EH7etst

plus you need 2x M4 screws and an old usb cable to connect the pins with the 5V and ground.

Closed 2025-01-02.

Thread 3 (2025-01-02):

X-Min größer als X-Max

Fredchenhh, 2025-01-02:
Hey,

versuche gerade es umzusetzen. Er beschwert sich beim compilieren, das X-Min größer ist als X-Max. Hab die werte gedreht, dann reagiert aber der Touchscreen nicht.

Hast du ne idee? Stimmen die Werte so?

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

Fredchenhh, 2025-01-02:
Habs schon selbst gelöst. Danke :D

  calibration:
    x_min: 280
    x_max: 3860
    y_min: 340
    y_max: 3860

  transform:
    mirror_x: true
    mirror_y: false

akuehlewind, 2025-01-02:
Danke dir. Habs angepasst im repo 👍

Closed 2025-01-02.

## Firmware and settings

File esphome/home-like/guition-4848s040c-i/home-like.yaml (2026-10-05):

############################################################
# SmartDisplay – iOS Home app–inspired Tiles UI
# Target device: Guition ESP32-4848S040C_I
# Resolution: 480×480
#
# Target hardware
# - Guition ESP32-4848S040C_I with ESP32-S3
# - Built-in ST7701S RGB display
# - Built-in GT911 capacitive touchscreen
#
# What this config does
# - Renders a wallpaper background + a 2x4 grid of “tiles” (LVGL).
# - Each tile shows: icon (MDI font), title, and a value line.
# - Tile taps publish a short-lived text_sensor event (smartdisplay_action)
#   so you can build Home Assistant automations on top.
# - Optional: the device can also call Home Assistant services directly
#   (toggle lights/switches/fans/covers, activate scenes/scripts, set fan preset,
#   set light brightness, set fan percentage, set cover position).
#
# The layout is inspired by common modern smart home UIs.
#
# How to customize
# 1) Edit the TILE1..TILE8 blocks below.
# 2) If you change icons, update the FONT GLYPHS block in the substitutions below.
#    Each glyph must appear exactly once — same icon on multiple tiles is fine, just list it once.
# 3) The 480×480 background image is loaded through BG_IMAGE.
#
# Tile configuration model
# - TILE*_TYPE defines the entity kind: light | fan | switch | scene | script | cover
# - TILE*_TAP_ACTION defines what happens on short tap:
#   auto | toggle | activate | fan_toggle_preset | custom
# - TILE*_LONGPRESS defines the long press mode: none | slider | action
#   slider: opens a value overlay — configure with TILE*_LONGPRESS_SLIDER + TILE*_LONGPRESS_OFF_VALUE
#   action: fires a different entity — configure with TILE*_LONGPRESS_ACTION*
# - TILE*_VALUE_MODE defines how the value line is rendered:
#   auto | brightness | percentage | preset | text
#
# Notes
# - DIRECT_ACTIONS="true" enables direct HA service calls from the device.
#   If "false", only the smartdisplay_action event is emitted.
# - In auto mode, values and long-press behavior are derived from TILE*_TYPE:
#   light -> brightness, fan -> percentage/preset, scene/script -> text
#
# What you must adapt before flashing
# 1) Secrets: API/OTA encryption key and WiFi credentials (in secrets.yaml)
# 2) TILE*_ENTITY / TILE*_STATE_ENTITY values for your Home Assistant setup
# The tested orientation places the USB-C connector at the bottom.
############################################################

substitutions:

  DIRECT_ACTIONS: "true"                           # true = call Home Assistant services directly, false = only emit action events
  ROOM_NAME: "Office"                              # room name shown in the top-left header
  TIME_24H: "true"                                 # true = 24h format, false = 12h format

  ## DIM settings
  AUTO_DIM: "true"                                 # true = enable auto dimming
  AUTO_DIM_TIMEOUT: "10"                           # seconds after last touch
  MAX_BRIGHTNESS: "100"                            # backlight brightness in percent
  DIM_BRIGHTNESS: "40"                             # dimmed backlight brightness in percent
  NIGHT_MODE: "true"                               # true = use separate dim level at night
  NIGHT_START_HOUR: "22"                           # 0-23
  NIGHT_END_HOUR: "7"                              # 0-23
  NIGHT_DIM_BRIGHTNESS: "18"                       # backlight brightness in percent at night

  # ============================================================
  # UI TEXT / LOCALIZATION
  # The {title} placeholder can appear anywhere in a question.
  # ============================================================
  UI_CONFIRM_OFF_QUESTION: "Turn off {title}?"
  UI_CONFIRM_CLOSE_QUESTION: "Close {title}?"
  UI_CONFIRM_FALLBACK_TITLE: "this device"
  UI_CANCEL: "Cancel"
  UI_TURN_OFF: "Turn off"
  UI_CLOSE: "Close"
  UI_COLOR: "Color"
  UI_TEMPERATURE_SHORT: "Temp."
  UI_BRIGHTNESS: "Brightness"
  UI_CURRENT: "Current"
  UI_HUMIDITY: "Humidity"
  UI_SET_TO: "SET TO"
  UI_CLIMATE_MODE_OFF: "Off"
  UI_CLIMATE_MODE_HEAT: "Heat"
  UI_CLIMATE_MODE_COOL: "Cool"
  UI_CLIMATE_MODE_HEAT_COOL: "Heat/Cool"
  UI_CLIMATE_MODE_AUTO: "Auto"
  UI_CLIMATE_MODE_DRY: "Dry"
  UI_CLIMATE_MODE_FAN: "Fan"
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

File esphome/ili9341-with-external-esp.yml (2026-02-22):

############################################################
# SmartDisplay (External ESP wiring variant) – ESPHome + LVGL lockscreen UI
#
# Target hardware
# - Any ESP32 + external ILI9341 (320x240) display + XPT2046 touchscreen
# - This file uses a specific “external ESP” pinout (see wiring below).
#
# Purpose
# - LVGL renders a simple “lockscreen” UI: time/date + 4 toggle buttons.
#
# Touch input → Home Assistant
# - Every touch publishes an “action” string via a text_sensor:
#     sensor.smartdisplay_action = "btn1_press" / "btn2_press" / "btn3_press" / "btn4_press"
# - The sensor is auto-reset to "" after each press so repeated presses trigger reliably.
#
# Two supported control modes (choose what fits your setup)
# 1) Direct control (DEFAULT, simplest)
#    - DIRECT_ACTIONS: "true" (default)
#    - Each touch will:
#        • publish the action string AND
#        • directly call a Home Assistant service
#          (default: light.toggle on BTN*_ENTITY)
#    - Use this if you simply want to toggle lights without creating automations.
#
# 2) Automation-only control (custom logic)
#    - DIRECT_ACTIONS: "false"
#    - Each touch will ONLY publish the action string.
#    - You implement the behavior in Home Assistant automations using:
#        Trigger → State → sensor.smartdisplay_action → To: btn1_press (etc.)
#
# If you do NOT want to toggle lights
# - Either change the homeassistant.action blocks to a different service
#   (e.g. switch.toggle, script.turn_on, scene.turn_on, ...)
# - Or set DIRECT_ACTIONS to "false" and handle everything via HA automations.
#
# UI updates
# - On boot, every minute, and whenever the configured HA entities change
#   (mirrored into ESPHome to keep LVGL button states in sync).
#
# Hardware / wiring used by this variant (external ESP pinout)
# - Display SPI: CLK=GPIO18, MOSI=GPIO23, MISO=GPIO19
# - Touch SPI:   CLK=GPIO25, MOSI=GPIO32, MISO=GPIO35
# - Display: CS=GPIO27, DC=GPIO26, RESET=GPIO16
# - Touch:   CS=GPIO33, IRQ=GPIO34
# - Backlight PWM: GPIO4
#
# What you must adapt before flashing
# 1) Secrets: api.encryption.key, ota.password, WiFi credentials (prefer secrets.yaml)
# 2) Wiring: ensure your display + touch wiring matches the pinout above
# 3) BTN*_ENTITY: Home Assistant entity IDs you want to control/mirror
# 4) Touch calibration + transform:
#    - calibration is panel-specific
#    - touchscreen.transform MUST match display.transform exactly
#
# Home Assistant note
# - In the ESPHome device settings, enable:
#   “Allow the device to perform Home Assistant actions”
#   Otherwise homeassistant.action calls are blocked.
############################################################

# ==========================================================
# USER CONFIG (edit this section to match your HA setup)
#
# - DIRECT_ACTIONS:
#     "true"  -> touch publishes action + calls HA service (light.toggle by default)
#     "false" -> touch only publishes action (all logic handled in HA)
#
# - BTN*_ENTITY:
#     The Home Assistant entity to control and mirror for the button state.
#     Must exist in Home Assistant.
#
# - BTN*_LABEL / BTN*_ICON:
#     Only affects what is shown on the display.
# ==========================================================
substitutions:
  # Enable/disable direct Home Assistant service calls on touch.
  # - "true"  -> touching a button also calls light.toggle (plug & play)
  # - "false" -> touching a button ONLY publishes the action text_sensor
  DIRECT_ACTIONS: "true"

  # Button 1
  BTN1_ENTITY: "light.desk_lamp"
  BTN1_LABEL: "Desk"
  BTN1_ICON: "\U000F095F"

  # Button 2
  BTN2_ENTITY: "light.ceiling_light"
  BTN2_LABEL: "Ceiling"
  BTN2_ICON: "\U000F0769"

  # Button 3
  BTN3_ENTITY: "light.globe_lamp"
  BTN3_LABEL: "Globe"
  BTN3_ICON: "\U000F08DD"

  # Button 4
  BTN4_ENTITY: "light.ambient_light"
  BTN4_LABEL: "Ambient"
  BTN4_ICON: "\U000F1051"
# ==========================================================

esphome:
  name: smartdisplay
  friendly_name: SmartDisplay
  on_boot:
    priority: 600
    then:
      - script.execute: ui_refresh

esp32:
  board: esp32dev
  framework:
    type: arduino

logger:

api:
  encryption:
    key: "XXXXXXXXXXXXXXXXXXXXXXXXXXXXXXXXXX"

ota:
  - platform: esphome
    password: "XXXXXXXXXXXXXXXXXXXXXXXXXXXXXXXXXX"

wifi:
  ssid: !secret wifi_ssid
  password: !secret wifi_password
  ap:
    ssid: "Smartdisplay Fallback Hotspot"
    password: "XXXXXXXXXXXXXXXXXXXXXXXXXXXXXXXXXX"

captive_portal:

# Use Home Assistant time so the display always matches your HA timezone.
time:
  - platform: homeassistant
    id: homeassistant_time
    on_time:
      - seconds: 0
        minutes: /1
        then:
          - script.execute: ui_refresh
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

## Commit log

2026-02-21 feat: migrate to LVGL-based UI and update YAML configs
    - Replaced legacy display lambda with ESPHome LVGL UI
    - Implemented centralized ui_refresh synchronization logic
    - Switched to homeassistant.action for direct service calls
    - Updated esp32-2432s028.yml and external wiring variant
    - Refactored README to reflect new architecture
    - Added documentation for enabling Home Assistant Actions
    - Clarified Cheap Yellow Display (CYD) support
    [esp32-2432s028.yml, ili9341-with-external-esp.yml]
2026-02-22 refactor: add button substitutions + document USER CONFIG in README
2026-02-24 feat: introduce home-like UI variant and improve documentation structure
    Add tile-based LVGL interface for both CYD and external ESP32 + ILI9341 variants.
    Refactor README to clarify hardware options, UI variants, assets, and setup instructions.
2026-03-04 added on-desk-mount option
    [Touch-Display.3mf, desk-mount.stl, desk-stand-touch-display.f3d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]
2026-03-14 feat: add wall mount variant for CYD enclosure
    [Touch-Display.3mf, wall-mount-touch-display.f3d, wall-mount-touch-display.stl]
2026-03-16 docs: document CYD power wiring for mount enclosure and add reference image
2026-03-18 docs: add warning about correct JST power connector on CYD
2026-03-25 reorganize 3D print folder and introduce flush mount (in-wall) option
    [Touch-Display.3mf, desk-mount.stl, desk-stand-touch-display.f3d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]
2026-03-25 fix: coloring in bambulabs file
    [Touch-Display.3mf]
2026-03-26 docs: fix README inconsistencies and bundle MDI font
    - Correct background image path tips (was ../images/ and /images/, actual ESPHome path is images/)
    - Clarify wall mount and flush mount are CYD-only in 3D print section
    - Bundle materialdesignicons-webfont.ttf (Apache 2.0) so no manual download is needed
    - Update font comments in all YAML files to reflect bundled font
2026-03-26 refactor: normalize 3d_print folder structure for ILI9341
    - Rename mount.3mf and Touch-Display.3mf to touch-display.3mf (kebab-case)
    - Move ILI9341 variant STLs into variants/ subfolders to match ESP32 structure
    [desk-mount.stl, touch-display.3mf, under-desk-mount.stl]
2026-03-26 fix: rename home-like.yml to home-like.yaml for consistent file extensions
    [home-like.yaml]
2026-04-01 feat: add orientation support to home-like UI (0°/90°/180°/270°)
    - Add ORIENTATION preset block to cyd and ili9341 home-like.yaml with
    substitution variables for display/touch transforms, tile grid layout,
    tile content positions, overlay sizes, and background image
    - Four commented presets (0°, 90°, 180°, 270°) — uncomment to switch
    - Portrait layout stacks title and value below the icon
    - Add smartdisplay_background_90.png for portrait orientation
    - Fix was_on lambda indentation in on_long_press for all tiles (both variants)
    - Add cover tile support fixes: correct was_on logic, slider label globals,
    YAML parse error from misindented lambda bodies
    - Update README: orientation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
    [home-like.yaml]
2026-04-02 refactor: reorganize esphome folder by UI type and improve documentation
    - Restructure esphome/ into home-like/ and buttons/ top-level folders,
    each containing cyd-2432s028/ and ili9341-external-esp32/ variants
    - Duplicate fonts/ and images/ into each UI folder for self-contained setup
    - Add TILE_CONFIGURATION.md with full substitution reference and copy-paste
    examples for light, switch, cover, fan, scene, script, and long press modes
    - Add README.md to home-like/ and buttons/ explaining hardware variants,
    required assets, and feature differences
    - Update root README with new paths and link to tile configuration doc
    - Redesign long press substitutions: TILE*_LONGPRESS now takes none|sl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
    [home-like.yaml]
2026-04-02 fix: skip touch-blocking overlay when DIM_BRIGHTNESS equals MAX_BRIGHTNESS
    When DIM and MAX brightness are equal the display does not visually dim,
    so there is no need to block touch input with the wake overlay. The device
    is still marked as dimmed to prevent the interval from re-firing every second.
    Night mode transitions continue to work correctly.
    [home-like.yaml]
2026-04-02 refactor: migrate credentials to secrets.yaml and clean up config structure
    - Replace CHANGE_ME/XXXXXXXXX placeholders with !secret references in all YAMLs
    - Rename secret keys: smartdisplay_ota_password → ota_password, smartdisplay_fallback_password → wifi_ap_password
    - Add secrets.yaml.example with all required keys and generation instructions
    - Move "No need to edit below this line" banner to end of substitutions block in all YAMLs
    - Add credential comment pointing to secrets.yaml.example near api/ota/wifi sections
    - Document secrets setup in home-like and buttons READMEs
    [home-like.yaml]
2026-04-22 fix: migrate display platform to mipi_spi for ESPHome 2026.4+ compatibility
    - Replace ili9xxx with mipi_spi across all four YAML variants
    - Remove color_palette: 8BIT (not supported by mipi_spi)
    - Remove miso_pin from LCD SPI bus (not required for display)
    - Bump required ESPHome version to 2026.4+
    - Add troubleshooting note for users on older ESPHome versions
    - Add CHANGELOG.md
    [home-like.yaml]
2026-04-26 fix: prevent duplicate glyph error when same icon is used on multiple tiles
    Introduce a dedicated MDI_GLYPH_1..6 substitution block as the single
    source of truth for the MDI font glyph list. TILE*_ICON variables now
    reference glyphs freely without ending up in the font definition,
    eliminating the "Found duplicate glyph" ESPHome error.
    [home-like.yaml]
2026-05-02 docs: add assembly guides for CYD and ILI9341 hardware variants
    Step-by-step instructions covering part selection, mounting order,
    power cable routing (CYD: JST through body; ILI9341: rear cutout
    for direct pin access), and enclosure assembly.
2026-06-01 Add advanced home-like light and climate controls
    Adds color and color-temperature controls for supported lights, including preset colors, Kelvin presets, adaptive Color/Temp tabs, and brightness adjustment.
    Adds climate tile support with thermostat ring control, half-degree target temperature steps, clickable HVAC mode cycling, live Home Assistant sync while the overlay is open, and per-tile climate sub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
    Updates the README, tile configuration reference, and changelog for the new home-like controls.
2026-06-21 fix: handle display rotation via LVGL for ESPHome 2026.6 compatibility
    ESPHome 2026.6 rejects a mipi_spi display transform combined with swapped
    dimensions ('Invalid offsets', #23). Rotation is now handled by LVGL: the
    display runs at its native 240x320 with no transform, and orientation is
    driven by a new LVGL_ROTATION substitution feeding 'lvgl: rotation:' (LVGL
    rotates display and touch together). Touch transform becomes a constant
    native-axis correction across all orientation presets.
    Also add per-device .gitignore entries for build symlinks and local test
    configs, and document the required ESPHome version plus a troubleshooting
    entry in the README.
    [home-like.yaml]
